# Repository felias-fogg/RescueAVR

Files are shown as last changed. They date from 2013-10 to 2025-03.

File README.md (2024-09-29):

# RescueAVR





This sketch can resurrect many classic AVR chips with wrong fuse settings using high-voltage (HV) programming. 

Sometimes, you may erroneously set a fuse bit, such as the clock source bit, and then the chip does not respond to ISP programming anymore. In this case, HV programming can help. One can easily reset all fuses to their factory setting, and then ISP programming is possible again. Note that the sketch does not implement a general HV programmer but can only perform some basic tasks, such as fuse setting and erasing the entire chip. Furthermore, you should not apply this technique "in-system" without pre-cautions. HV programming means that you apply 12 V to the RESET pin. So, if you do that "in-system," you should make sure that the RESET line is not connected to the rest of the system (e.g., by a pull-up resistor). 

To do HV programming, you need an Arduino Uno, Nano, Pro Mini, Leonardo, or Mega(2560), a breadboard, a PNP/NPN transistor pair, a few resistors, many jumper wires, and an external regulated 12-volt supply. If you are the happy owner of a *RecueAVR shield* for an Arduino Uno/Mega, everything is already included and set up, including the 12 V source. You can build such a shield using the KiCAD design files in the [PCB directory](pcb/) or buy the [PCBs or a kit at Tindie](https://www.tindie.com/products/35748/). The [assembly process](pcb/assembly.md) is straightforward and involves only THT components.

Furthermore, the sketch is also an alternative firmware for [manekinen's Fusebit Doctor](https://web.archive.org/web/20180225102717/http://mdiy.pl/atmega-fusebit-doctor-hvpp/?lang=en). The pin mapping is different between these two versions. When the sketch is compiled for an Arduino Uno, Nano, Pro (Mini), Leonardo, or Mega(2560) in the Arduino IDE, it will use the Arduino Uno pin mapping. Otherwise, it uses the pin mapping for the Fusebit Doctor. One can also force which version is produced by defining the compile-time constants  `ARDUINO_MODE` or `FBD_MODE`, respectively.

By now, the sketch covers 131 different MCU types and has been tested on most of the types that are available in DIP packages.

When using the sketch, remember to set the monitor baud rate to 19200 baud (no parity, 1 stop-bit). A [user manual](docs/manual.md) for the sketch is provided in the docs folder.

The sketch uses many of the ideas and code of [MightyOhm's HV Rescue Shield 2](https://mightyohm.com/blog/products/hv-rescue-shield-2-x/) and is inspired by [manekinen's Fusebit Doctor](https://web.archive.org/web/20180225102717/http://mdiy.pl/atmega-fusebit-doctor-hvpp/?lang=en).

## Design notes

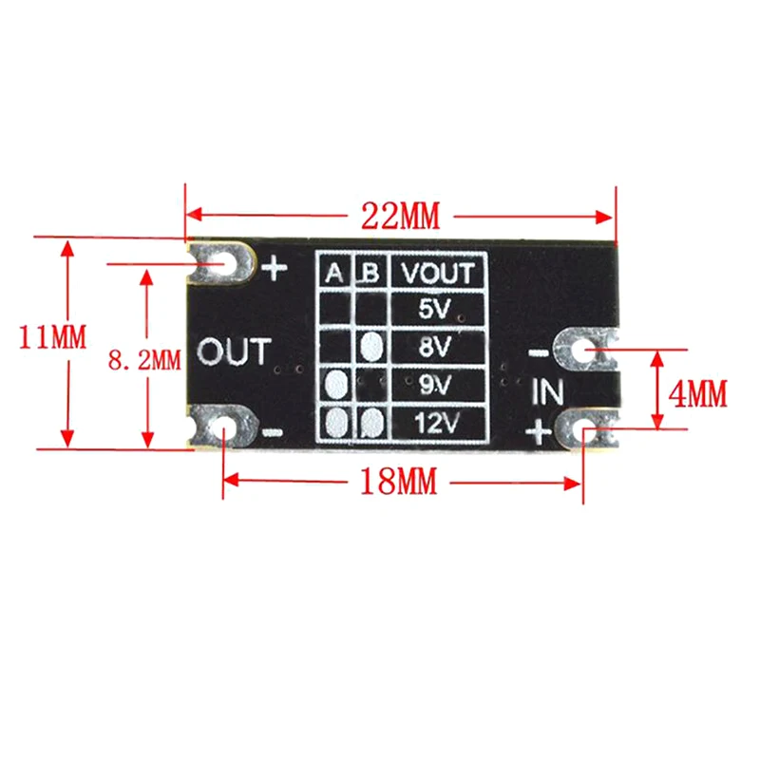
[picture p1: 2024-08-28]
pcb/boost.jpg

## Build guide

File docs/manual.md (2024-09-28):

# RescueAVR Manual

The RescueAVR sketch can be used to rescue bricked AVR MCUs. You can run it on a UNO (or similar) with the target chip on a breadboard, or you can use it to drive the [RescueAVR shield (+ adapter board)](../pcb/), which [you can buy at Tindie](https://www.tindie.com/products/fogg/rescueavr-hv-fuse-programmer-for-avrs/). Finally, it can be used as an alternative firmware for the [Fusebit Doctor](https://web.archive.org/web/20180225102717/http://mdiy.pl/atmega-fusebit-doctor-hvpp/?lang=en).

One word of caution: Since the GPIO pins of two different MCUs will be directly connected to each other, you should upload the sketch __before__ connecting the target chip to the UNO board (or plugging in the RescueAVR shield). Otherwise, you risk short-circuiting a GPIO pin with an active high level to GND, which might destroy the chip.

Remember to set the monitor baud rate to 19200 baud (no parity, 1 stop-bit) when you use the sketch.

### Using RescueAVR on an Arduino Uno with a Breadboard

Below, you will find Fritzing wiring schemes for an ATtiny85, an ATtiny84, and an ATmega328. The complete list of supported chips can be found in [Appendix A](#appendixa). For chips other than the ATtinyX5, ATtinyX4, and ATmega(X)8, you need to consult the particular microcontroller's datasheet. The pin mapping can be found in the Memory Programming Section of each data sheet. For some popular MCUs, I have included wiring instructions for the DIP/SOIC versions of the chips in [Appendix B](#appendixb).

The most crucial part of high-voltage programming is the ability to put 12 volts into the RESET pin of the MCU. So, you need a regulated 12-volt supply and an electronic switch that applies this voltage to the RESET pin. Such a switch using two transistors is shown below. The transistors I have used are pretty standard ones. You can use any other reasonable type. But make sure that the pins are ordered as in the picture, i.e., CBE (otherwise, the Fritzing diagram is incorrect).

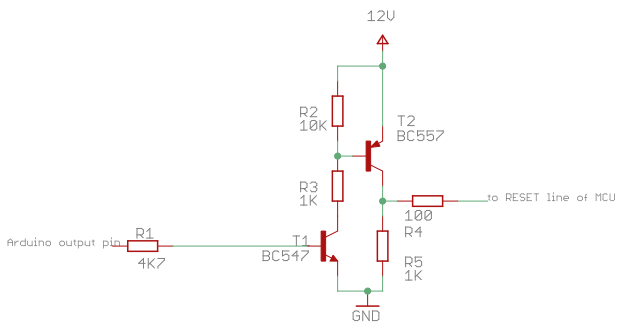
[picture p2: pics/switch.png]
12V switch


The wiring is straightforward for small ATtinys because they use serial programming, and you need only a few wires. The Fritzing diagram for an ATtinyX5 looks as follows (and applies to ATtiny11, 12, 13, 22, and most other 8-pin MCUs).
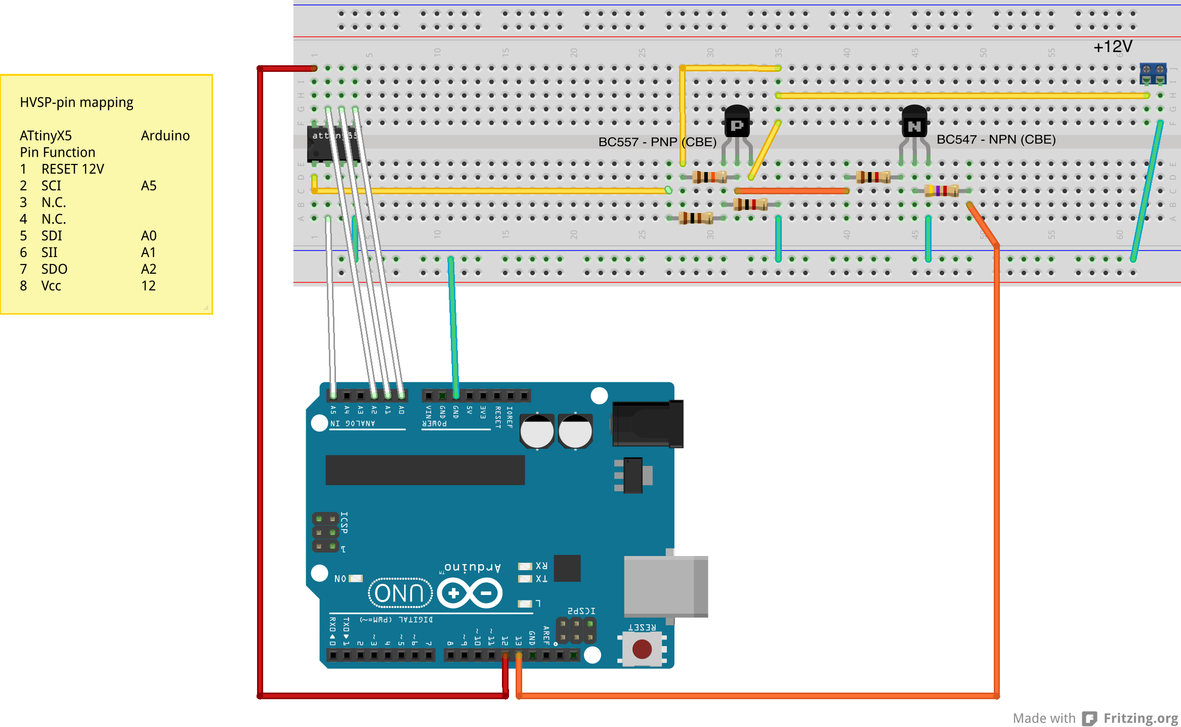
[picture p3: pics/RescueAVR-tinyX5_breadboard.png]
ATtinyX5 Fritzing sketch


Similarly, the wiring for an ATtinyX4 is quite simple as well. As you can see, one needs just 2 data lines (SDI, SDO), one clock line (SCI), and one control line (SII), and in addition, one has to switch the RESET line and the Vcc line. 
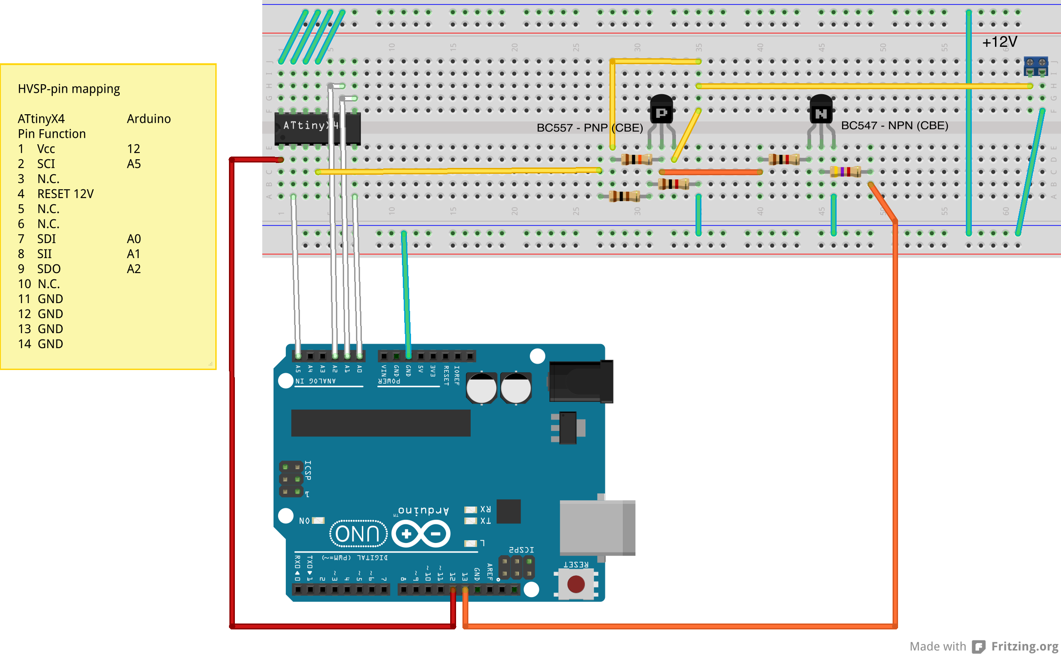
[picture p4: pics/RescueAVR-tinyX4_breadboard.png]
ATtinyX4 Fritzing sketch


The wiring for an ATmegaX8 MCU is much more involved. One has to deal with 8 data lines, one clock line, and 9 control lines! This may look like the following Fritzing diagram.
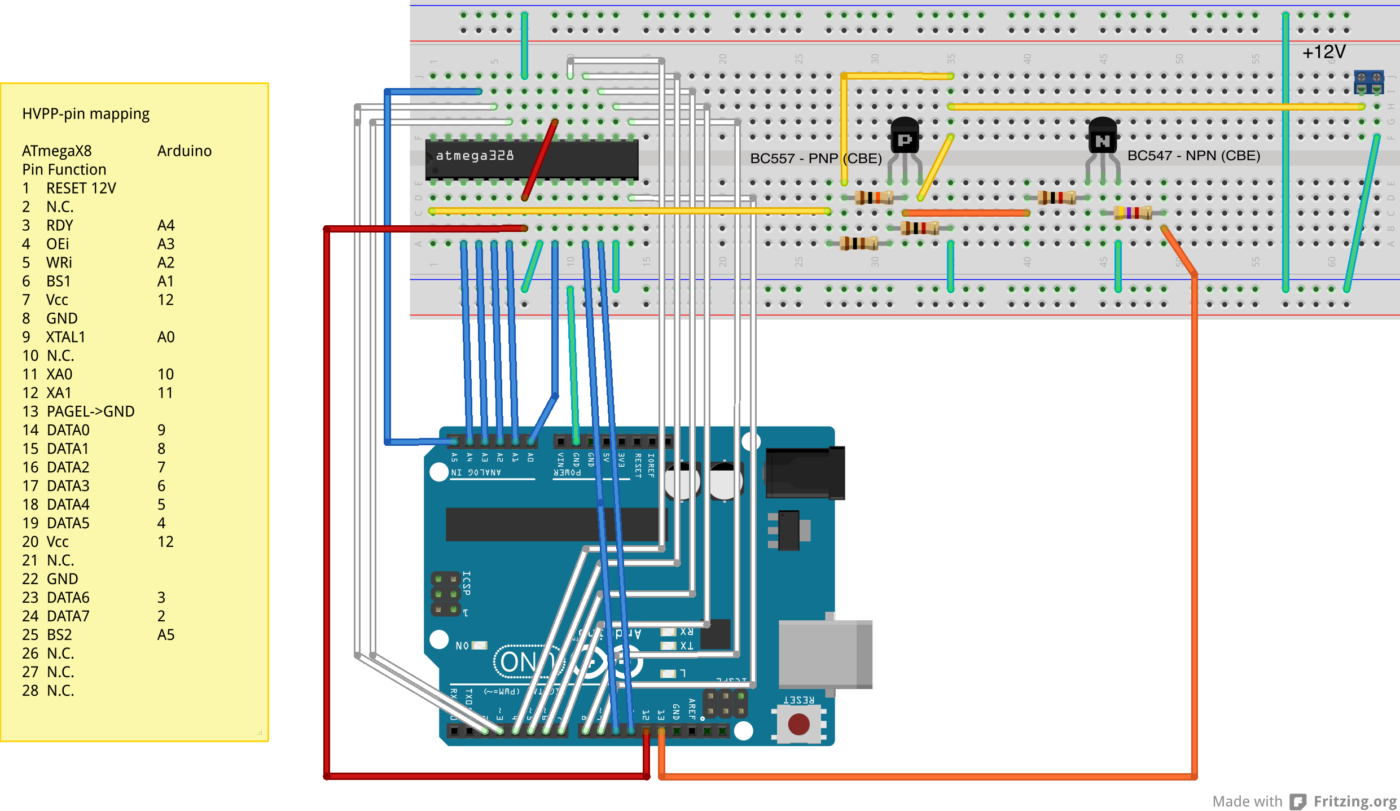
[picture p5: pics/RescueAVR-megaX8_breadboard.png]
ATmega Fritzing sketch


When this is put to work in reality, it can look as follows. Check the wiring twice before applying the external power. If 12 volt is applied to a pin that is not the RESET pin, the chip may easily die.


After you have made all the connections (and double-checked them!), open the Arduino monitor window, switch to 19200 baud, switch on the external power supply, and press the reset button of the Arduino UNO. You are now in interactive rescue mode and can do many things (see below).

### Using RescueAVR with a RescueAVR Shield

The RescueAVR shield can be directly plugged into an Arduino UNO board. It has an onboard step-up converter, so you do not need an external voltage source for high-voltage programming. It provides two SIL sockets for HVPP and HVSP. In addition, it contains DIP sockets for the ATinyX5 series, the ATtinyX4 series, and the ATmega(X)8 series. 

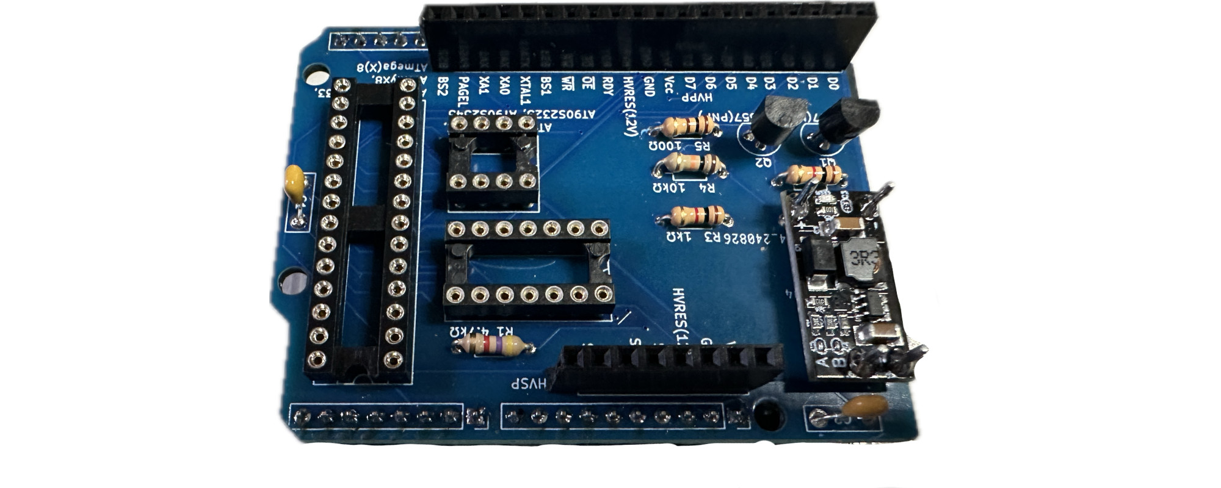
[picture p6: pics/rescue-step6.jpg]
RescueAVR


For the ATtinyX6(1) series, the ATtiny(X)232 series, the ATmegaX3, X4, 8535, the ATmega162, 8515, and pin-compatible chips, one can use an adapter board that plugs into the HVPP/HVSP pin sockets. 

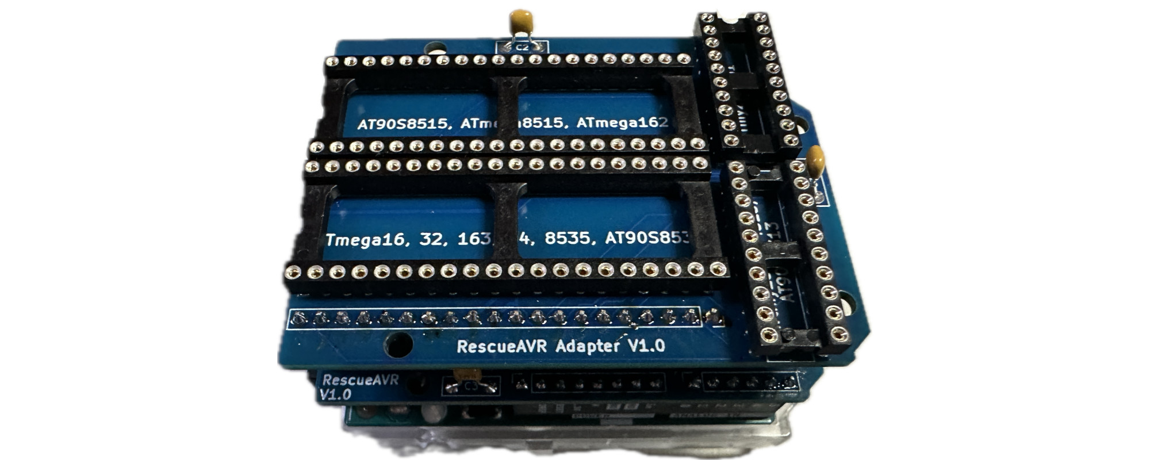
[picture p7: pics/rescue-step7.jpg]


Before you plug in the target chip, you should plug in the shield on the UNO. After connecting the UNO board to a PC, you will enter interactive rescue mode, as described below.

### Using RescueAVR on the Fusebit Doctor

The Fusebit Doctor can be run stand-alone or connected to a computer. In the stand-alone mode (no serial communication lines connected to a computer), after power-up, all LEDs are off, and you can insert a chip. After pressing the button, the board will first try to recognize the chip:

- The green LED is on for three seconds: chip has been successfully recognized,
- the green LED is on for one second, and then the red LED is on for three seconds: The chip has been recognized, but there is not enough information in the firmware to resurrect it,
- the red LED is on for three seconds: no chip has been recognized.

After recognizing the MCU, the board checks whether any lock bits are set. If this is not the case, it tries to set the fuses to a safe default setting. If successful, the green LED flashes for 5 seconds; otherwise, the red LED flashes for 5 seconds. If unsuccessful, you can try to set the erase jumper, which allows for erasing the entire chip (including the lock bits) in order to recover it.

If the board's serial line is connected to a computer using 19200 baud (no parity, 1 stop-bit), you can use the ***interactive rescue mode***, which gives you more control than the stand-alone mode.

### Interactive Rescue Mode

To use RescueAVR in interactive mode, you should be connected to the Fusebit Doctor or Arduino by a serial line with 19200 baud, 1 stop bit, and no parity. This can be accomplished using the Arduino monitor window or any serial line client (e.g., cu, screen, or PuTTY). 

When switched on or after a reset, the sketch will try to determine what kind of programming mode the MCU uses and which MCU is connected. If unsuccessful, the following is displayed:

	No chip found!
	Insert chip and restart or give details.
	
	Choose from:
		P - HVPP
		T - HVPP for Tiny
		S - HVSP
		1 - HVSP for Tiny15
		R - Start again
	Choice: 

When this message is shown, you either forget to insert the MCU, the wiring is wrong, the external power supply is not switched on, or the chip is badly damaged. In the latter case, you might try then to select the programming mode, where *HVPP* is the high-voltage *parallel* programming mode for ATmegas, *HVPP for Tiny* is the same mode for ATtinys (PAGEL and BS1 are both controlled by BS1, and BS2 and XA1 are both controlled by BS2, so PAGEL and XA1 should not be connected to the chip). *HVSP* is the high-voltage *serial* programming mode for ATtinyX4(1) and 8-pin chips, *HVSP for Tiny15* is the serial mode for the ATtiny15. After selecting a programming mode, you can set fuses and lock bits. However, I have never been successful when the MCU could not be identified anymore. In any case, there is more likely a wiring error, or you forgot to plug the MCU into the socket (or breadboard).

Usually, the chip is detected, and something along the following lines is printed.

	Signature: 1E910A
	MCU name:  ATtiny2313
	HV type:   HVPP for Tiny
	Current L/H/E-Fuses: 63 DF FF 
	Default L/H/E-Fuses: 62 DF FF 
	Current lock byte:   FF 
	Oscillator calibr.:  61 

You can then choose from the following menu.

	Choose:
		T - Try to resurrect chip by all means
		E - Erase chip
		D - Burn default fuse values
		L - Change low fuse
		H - Change high fuse
		X - Change extended fuse
		K - Change lock byte
		R - Restart
	Action: 

If you are only interested in unbricking your chip, press 'T'. This will check whether lock bits are set, and if so, it will try to erase the chip (if the 'chip erase' jumper on the Fuse-Doctor board is set). After that, it will try to reset the fuses to their default value. If 'T' does not help, you can say 'goodbye' to the chip. 

The other options are all self-explanatory. If you want to change individual fuses, you may wish to consult the online fuse calculator [AVR Fuse Calculator](https://www.engbedded.com/fusecalc/) by Mark Hämmerling or the chip datasheet. The same goes for the lock byte.

When using the Arduino monitor window, you can enter a new fuse value immediately after the command. For example, typing `L7F` will change the low fuse to 0x7F (if possible).

### Appendix A: Supported MCUs

The sketch works with all currently available *classic* AVR chips (i.e., mainly those that can be programmed using ISP) and a few obsolete ones. Here is the list of supported MCUs (currently 131). The **bold** ones can be programmed using the RescueAVR shield by plugging the chip with a DIP footprint into one of the shield IC sockets. I have tested the *italics* ones.

- AT90CAN32, AT90CAN64, AT90CAN128
- AT90PWM1/AT90PWM2B/AT90PWM3B
- AT90PWM2/AT90PWM3
- AT90PWM216/AT90PWM316
- AT90PWM81, ATP90WM161
- AT90USB646/7, AT90USB1286/7
- AT90USB82, AT90USB162
- **AT90S1200,** ***AT90S2313***
- **AT90S2333, *AT90S4433***
- ***AT90S2323*, AT90S2343**
- **AT90S4434, *AT90S8535***
- **AT90S4414**, ***AT90S8515***
- ___ATtiny11___
- ***ATtiny12***
- **ATtiny22**
- ***ATtiny13***
- ATtiny43U
- ***ATtiny2313***, ***ATtiny4313***
- ***ATtiny24***, ***ATtiny44***, ***ATtiny84***
- *ATtiny441*, ATtiny841
- *ATtiny15*, 
- ***ATtiny25*, *ATtiny45*, *ATtiny85*** 
- ***ATtiny2*6**
- ***ATtiny261*, *ATtiny461*, *ATtiny861***
- ATtiny87, ATtiny167
- **ATtiny28**
- ***ATtiny48*, *ATtiny88***
- ATtiny828
- ATtiny1634
- ***ATmega8515***
- ***ATmega8535***
- ***ATmega8***, ATmega8HVA, ATmega8HVB
- **ATmega16**, ATmega16HVA, ATmega16HVB, ATmega16M1, ***ATmega32***, ATmega32C1, ATmega32M1, ATmega32HVB, ATmega64, ATmega64C1, ATmega64HEV2, ATmega64M1, ATmega64RFR2, ATmega128, ATmega128RFA1, ATmega128RFR2, ATmega256RFR2
- ATmega640, ATmega1280, ATmega1281, ATmega2560, ATmega2561
- **ATmega161**, ***ATmega162***
- ATmega103
- ***ATmega163***, **ATmega323**
- **ATmega164, ATmega164P, ATmega324, ATmega324P**, Atmega324PB, **ATmega644, ATmega644P**, ATmega644RFR2, **ATmega1284, *ATmega1284P*,** ATmega1284RFR2, ATmega2564RFR2
- ATmega165, ATmega165P, ATmega325, ATmega325P, ATmega3250, ATmega3250P, ATmega645, ATmega645P, ATmega6450, ATmega6450P
- ATmega406
- ***ATmega48*, *ATmega48P*,** ATmega48PB, ***ATmega88***, ***ATmega88P***, ATmega88PB, ***ATmega168*, *ATmega168P*,** ATmega16PB, ***ATmega328***, ***ATmega328P***, ATmega328PB
- ATmega169, ATmega169P, ATmega329, ATmega329P, ATmega3290, ATmega3290P, ATmega649, ATmega649P, ATmega6490, ATmega6490P
- ATmega8U2, ATmega16U2, ATmega32U2
- ATmega16U4, ATmega32U4

### Appendix B: Wiring tables for DIP/SOIC variants of some MCUs

The wiring tables below apply only to the SOIC/DIP versions of the respective MCU types. 

#### ATtiny11, 12, 13, 22, 25, 45, 85, AT90S2323, 2343 (HVSP)

| ATtiny pin | Function | Arduino UNO pin name |
| --- | --- | --- |
| 1 | !RESET(12V switchable) | (triggered by 13) |
| 2 | SCI | A5 |
| 3 | | |
| 4 | GND | GND |
| 5 | SDI | A0 |
| 6 | SII | A1 |
| 7 | SDO | A2 |
| 8 | Vcc | 12 |

#### ATtiny15 (HVSP for Tiny15)

| ATtiny pin | Function | Arduino UNO pin name |
| --- | --- | --- |
| 1 | !RESET(12V switchable) | (triggered by 13) |
| 2 | | |
| 3 | SCI | A5 |
| 4 | GND | GND |
| 5 | SDI | A0 |
| 6 | SII | A1 |
| 7 | SDO | A2 |
| 8 | Vcc | 12 |

#### ATtiny24, 44, 84, 441, 841 (HVSP)

| ATtiny pin | Function | Arduino UNO pin name |
| --- | --- | --- |
| 1 | Vcc | 12 |
| 2 | SCI | A5 |
| 3 | | |
| 4 | !RESET(12V) | (triggered by 13) |
| 5 | | |
| 6 | | |
| 7 | SDI | A0 |
| 8 | SII | A1 |
| 9 | SDO | A2 |
| 10 | | |
| 11 | GND | |
| 12 | GND | |
| 13 | GND | |
| 14 | GND | |

#### ATtiny2313 and 4313, AT90S1200, 2313 (tiny HVPP)

| ATtiny Pin | Function | Arduino UNO pin name |
| --- | --- | --- |
| 1 | !RESET  (12V switchable) | (triggered by 13) |
| 2 | | |
| 3 | RDY | A4 |
| 4 | | |
| 5 | XTAL1 | A0 |
| 6 | !OE | A3 |
| 7 | !WR | A2 |
| 8 | **BS1**/PAGEL | A1 |
| 9 | XA0 | 10 |
| 10 | GND | GND |
| 11 | XA1/**BS2** | A5 |
| 12 | DATA0 | 9 |
| 13 | DATA1 | 8 |
| 14 | DATA2 | 7 |
| 15 | DATA3 | 6 |
| 16 | DATA4 | 5 |
| 17 | DATA5 | 4 |
| 18 | DATA6 | 3 |
| 19 | DATA7 | 2 |
| 20 | Vcc (5V) | 12 |

#### ATtiny26, ATtiny261, ATtiny461, ATtiny861 (tiny HVPP)

| ATtiny pin | Function | Arduino pin name  |
| --- | --- | --- |
| 1 | !WR | A2 |
| 2 | XA0 | 10 |
| 3 | XA1/**BS2** | A5 |
| 4 | PAGEL/**BS1** | A1 |
| 5 | Vcc(5V) | 12 |
| 6 | GND | GND |
| 7 | XTAL1 | A0 |
| 8 | !OE | A3 |
| 9 | RDY | A4 |
| 10 | !RESET(12V) | (triggered by 13) |
| 11 | DATA7 | 2 |
| 12 | DATA6 | 3 |
| 13 | DATA5 | 4 |
| 14 | DATA4 | 5 |
| 15 | Vcc(5V) | 12 |
| 16 | GND | GND |
| 17 | DATA3 | 6 |
| 18 | DATA2 | 7 |
| 19 | DATA1 | 8 |
| 20 | DATA0 | 9 |

#### ATtiny87, ATtiny167 (tiny HVPP)

| ATtiny pin | Function | Arduino UNO pin name |
| --- | --- | --- |
| 1 | DATA0 | 9 |
| 2 | DATA1 | 8 |
| 3 | DATA2 | 7 |
| 4 | DATA3 | 6 |
| 5 | Vcc(5V) | 12 |
| 6 | GND | GND |
| 7 | DATA4 | 5 |
| 8 | DATA5 | 4 |
| 9 | DATA6 | 3 |
| 10 | DATA7 | 2 |
| 11 | | |
| 12 | RDY | A4 |
| 13 | !OE | A3 |
| 14 | XTAL1 | A0 |
| 15 | Vcc(5V) | 12 |
| 16 | GND | GND |
| 17 | PAGEL/**BS1** | A1 |
| 18 | XA1/**BS2** | A5 |
| 19 | XA0 | 10 |
| 20 | !WR | A2 |

#### ATtiny1634 (tiny HVPP)

| ATtiny pin | Function | Arduino UNO pin name |
| --- | --- | --- |
| 1 | | |
| 2 | DATA7 | 2 |
| 3 | DATA6 | 3 |
| 4 | DATA5 | 4 |
| 5 | DATA4 | 5 |
| 6 | DATA3 | 6 |
| 7 | DATA2 | 7 |
| 8 | DATA1 | 8 |
| 9 | DATA0 | 9 |
| 10 | GND | GND |
| 11 | Vcc(5V) | 12 |
| 12 | XTAL | A0 |
| 13 | | |
| 14 | | |
| 15 | !RESET(12V) | (triggered by 13) |
| 16 | !OE | A3 |
| 17 | !WR | A2 |
| 18 | **BS1**/PAGEL | A1 |
| 19 | XA0 | 10 |
| 20 | XA1/**BS2** | A5 |

#### ATtinyX8, ATmega8, ATmegaX8, AT90S2333, 4433 (HVPP)

| ATmega pin | Function | Arduino UNO pin name |
| --- | --- | --- |
| 1 | !RESET(12V) | (triggered by 13) |
| 2 | | |
| 3 | RDY | A4 |
| 4 | !OE | A3 |
| 5 | !WR | A2 |
| 6 | BS1 | A1 |
| 7 | Vcc | 12 |
| 8 | GND | GND |
| 9 | XTAL1 | A0 |
| 10 | | |
| 11 | XA0 | 10 |
| 12 | XA1 | 11 |
| 13 | PAGEL (not AT90SX33) | GND |
| 14 | DATA0 | 9 |
| 15 | DATA1 | 8 |
| 16 | DATA2 | 7 |
| 17 | DATA3 | 6 |
| 18 | DATA4 | 5 |
| 19 | DATA5 | 4 |
| 20 | Vcc | 12 |
| 21 | | |
| 22 | GND | GND |
| 23 | DATA6 | 3 |
| 24 | DATA7 | 2 |
| 25 | BS2 (not AT90SX33) | A5 |
| 26 | | |
| 27 | | |
| 28 | | |

#### ATmega16, ATmega32, ATmegaX3, ATmegaX4,  ATmega8535, AT90S8535 (HVPP)

| ATmega pin | Function | Arduino UNO pin name |
| --- | --- | --- |
| 1 | DATA0 | 9 |
| 2 | DATA1 | 8 |
| 3 | DATA2 | 7 |
| 4 | DATA3 | 6 |
| 5 | DATA4 | 5 |
| 6 | DATA5 | 4 |
| 7 | DATA6 | 3 |
| 8 | DATA7 | 2 |
| 9 | !RESET(12V) | (triggered by 13) |
| 10 | Vcc(5V) | 12 |
| 11 | GND | GND |
| 12 | | |
| 13 | XTAL1 | A0 |
| 14 | | |
| 15 | RDY | A4 |
| 16 | !OE | A3 |
| 17 | !WR | A2 |
| 18 | BS1 | A1 |
| 19 | XA0 | 10 |
| 20 | XA1 | 11 |
| 21 | PAGEL (only ATmega) | GND |
| 22 | | |
| 23 | | |
| 24 | | |
| 25 | | |
| 26 | | |
| 27 | | |
| 28 | | |
| 29 | | |
| 30 | Vcc(5V) | 12 |
| 31 | GND | GND |
| 32 | | |
| 33 | | |
| 34 | | |
| 35 | | |
| 36 | | |
| 37 | | |
| 38 | | |
| 39 | | |
| 40 | BS2 (only ATmega) | A5 |

#### AT90S4414, 8515, ATmega8515, 161, 162 (HVPP)

| ATmega pin | Function | Arduino pin name  |
| --- | --- | --- |
| 1 | DATA0 | 9 |
| 2 | DATA1 | 8 |
| 3 | DATA2 | 7 |
| 4 | DATA3 | 6 |
| 5 | DATA4 | 5 |
| 6 | DATA5 | 4 |
| 7 | DATA6 | 3 |
| 8 | DATA7 | 2 |
| 9 | !RESET(12V) | (triggered by 13) |
| 10 | | |
| 11 | RDY | A4 |
| 12 | !OE | A3 |
| 13 | !WR | A2 |
| 14 | BS1 | A1 |
| 15 | XA0 | 10 |
| 16 | XA1 | 11 |
| 17 | PAGEL (only ATmega) | GND |
| 18 | | |
| 19 | XTAL1 | A0 |
| 20 | GND | GND |
| 21 | | |
| 22 | | |
| 23 | | |
| 24 | | |
| 25 | | |
| 26 | | |
| 27 | | |
| 28 | | |
| 29 | | |
| 30 | | |
| 31 | | |
| 32 | | |
| 33 | | |
| 34 | | |
| 35 | | |
| 36 | | |
| 37 | | |
| 38 | | |
| 39 | BS2 (only ATmega) | A5 |
| 40 | Vcc(5V) | 12 |

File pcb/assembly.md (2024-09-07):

# RescueAVR Assembly

The basic kit and the full kit kit [can be bought at Tindie](https://www.tindie.com/products/fogg/rescueavr-hv-fuse-programmer-for-avrs/).

The basic kit consists of:

- one RescueAVR PCB
- one RescueAVR Adapter PCB
- one GTIWUNG Step-Up Converter (5V/12V)
- four soldering pins (to connect the step-up converter to the RescueAVR PCB)

The full kit contains in addition:

- one 8-pin IC socket
- one 14-pin IC socket
- one 28-pin (narrow) IC socket
- two 20-pin IC sockets
- two 40-pin IC sockets
- two 40-pin pin headers (to be broken up into one 6-pin, three 8-pin, one 10-pin, and one 20-pin header)
- one 8-pin pin socket
- one 20-pin socket
- five 100 nF capacitors
- five resistors (100 Ω, two 1 kΩ, 4.7 kΩ, 10 kΩ)
- one NPN transistor (BC547)
- one PNP transistor (BC557)

### Step 1: Install step-up converter

If the step-up converter is not already installed on the RescueAVR PCB, this is the first step. 

1. Insert the four soldering pins with the shorter side into the PCB.
2. Make sure the pins are straight and that the tip protrudes on the backside.
3. Place the step-up converter with the component side upwards on the pins.
4. Solder the pins to the step-up converter.
5. Solder the pins on the backside of the PCB.

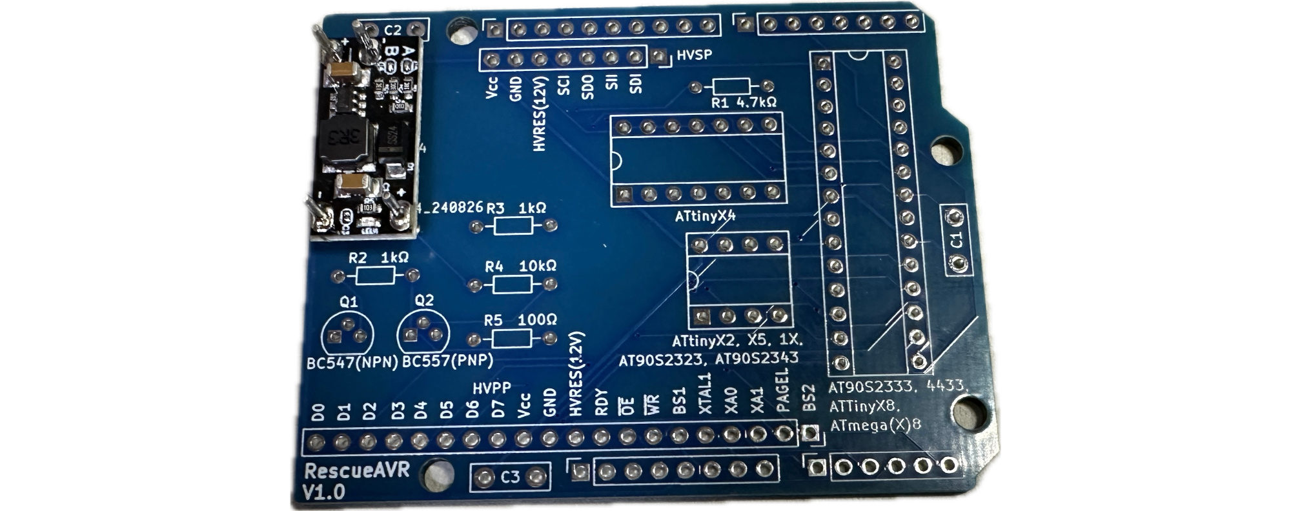
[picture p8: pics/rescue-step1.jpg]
Step1


### Step 2: Solder resistors

Solder the five resistors:

1. R1: 4.7 kΩ (yellow-violet-red)
2. R2: 1 kΩ (brown-black-red)
3. R3: 1 kΩ (brown-black-red)
4. R4: 10 kΩ (brown-black-orange)
5. R5: 100 Ω (brown-black-brown)

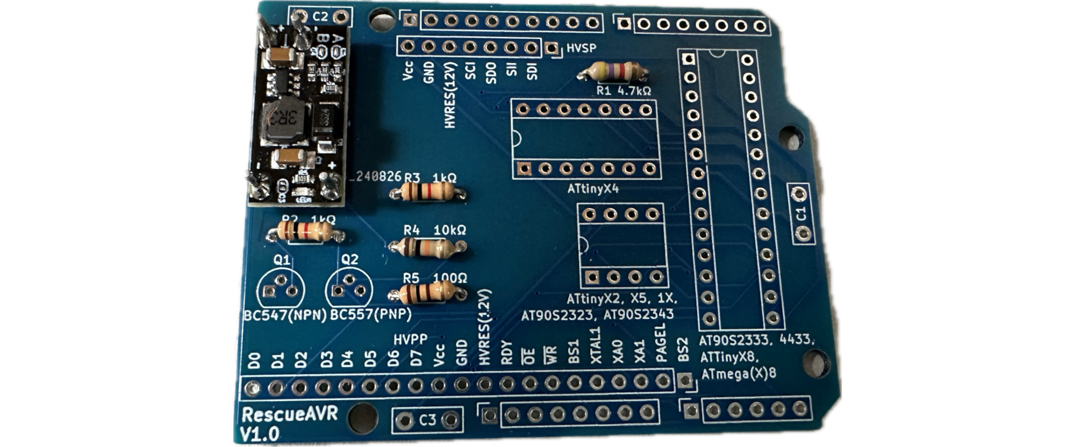
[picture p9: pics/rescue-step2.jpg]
Step2


### Step 3: Solder capacitors and transistors

1. Q1: BC547 (NPN)
2. Q2: BC557 (PNP)
3. C1-C3: 100 nF

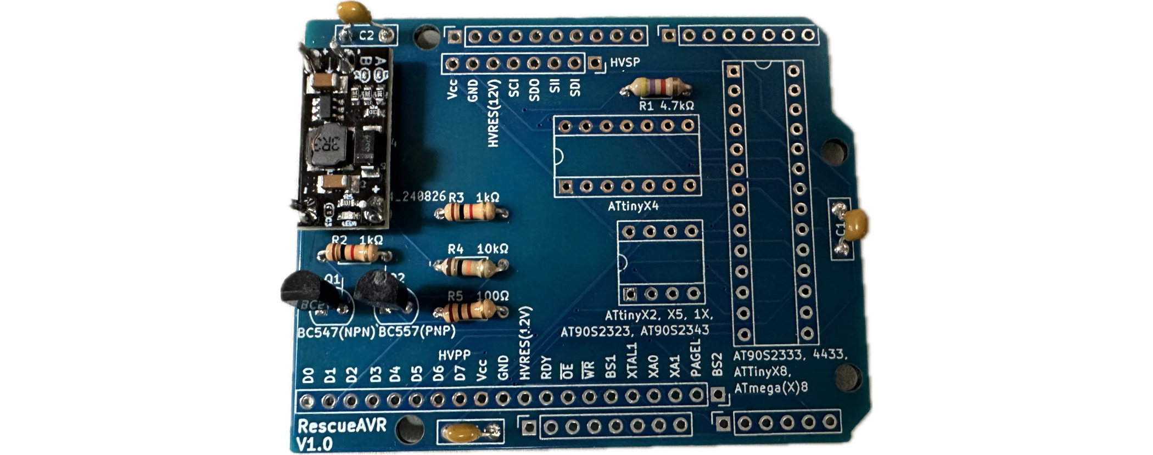
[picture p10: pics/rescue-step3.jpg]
Step3


### Step 4: Solder Arduino pin headers

Soldering the Arduino pin headers is preferrably done by placing the pin headers into the the pin sockets of an UNO and then placing the RescueAVR PCB on top of it. This way, you make sure that the pin headers are perfectly aligned.

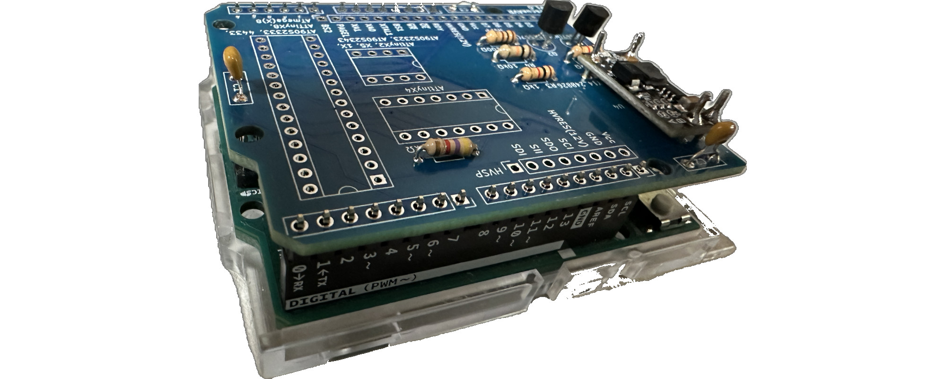
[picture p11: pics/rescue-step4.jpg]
Step4


### Step 5: Solder IC sockets

Insert the 8-pin, 14-pin, and 28-pin sockets into the PCB and solder them. Make sure to align the notches with the notches on the silkscreen. 

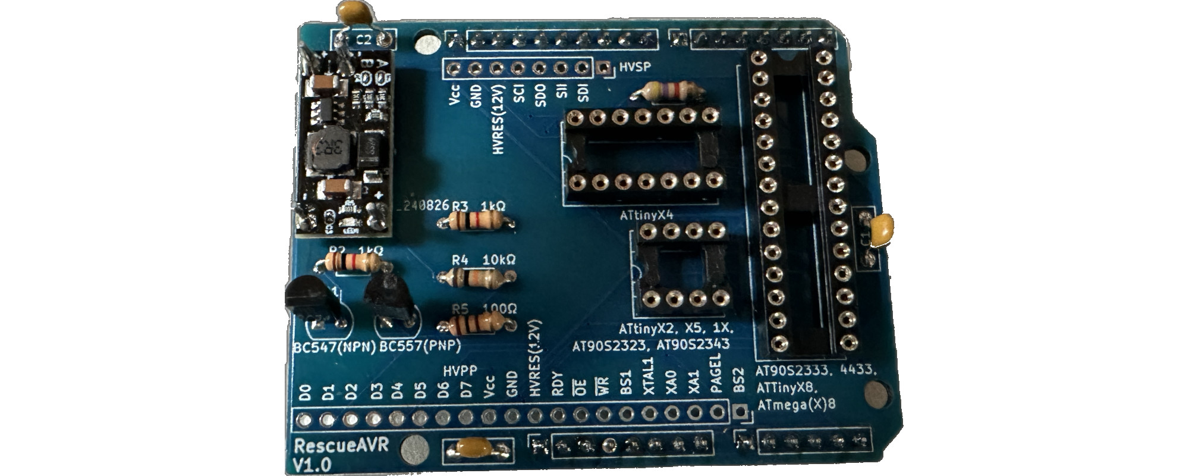
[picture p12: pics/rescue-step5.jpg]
Step5


### Step 6: Solder the pin sockets and the pin headers for the adapters

In order to ensure alignment, put the pinheaders into the sockets, put the socketes into the RescueAVR PCB and then put the adpater PCB on top. Now solder the pin sockets and headers. 

Step6

### Step 7: Solder IC sockets and capacitors to adapter

While soldering the two 40-pin and 20-pin sockets, ensure the notches align. 

Step7

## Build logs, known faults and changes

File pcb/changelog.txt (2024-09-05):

RescueAVR:

V1.0

- initial release

V1.1 (6.9.2024)

- modified silkscreen and 3D model

- removed ATtiny15

ReascueAVR Adapter:

V1.0

- initial release

V1.1

- added silkscreen: ATMega161, ATmegaX3, AT90S1200, AT90S4414

V1.2 (6.9.2024)

- moved silkscreen to the side so that it is always readable, modified
  3D model

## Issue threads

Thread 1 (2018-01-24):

Arduino IDE 1.8.5

bobybobybob, 2018-01-24:
Hello,
today i have repair my µC with your cable and code.  Work perfekt, thank you.

The new Arduino IDE give compiler error...  only have to add  const  on all

// The names of all MCUs known to us
const char at90s2313[] PROGMEM = "AT90S2313";
const char at90s2333[] PROGMEM = "AT90S2333";
const char at90s2343[] PROGMEM = "AT90S2343";
const char at90s4433[] PROGMEM = "AT90S4433";
const char at90s4434[] PROGMEM = "AT90S4434";
const char at90s8515[] PROGMEM = "AT90S8515";
const char at90s8535[] PROGMEM = "AT90S8535";
const char attiny11[] PROGMEM = "ATtiny11";
const char attiny12[] PROGMEM = "ATtiny12";
const char attiny13[] PROGMEM = "ATtiny13";
const char attiny15[] PROGMEM = "ATtiny15";
const char attiny2313[] PROGMEM = "ATtiny2313";
const char attiny4313[] PROGMEM = "ATtiny4313";
const char attiny24[] PROGMEM = "ATtiny24";
const char attiny44[] PROGMEM = "ATtiny44";
const char attiny84[] PROGMEM = "ATtiny84";
const char attiny25[] PROGMEM = "ATtiny25";
const char attiny45[] PROGMEM = "ATtiny45";
const char attiny85[] PROGMEM = "ATtiny85";
const char attiny26[] PROGMEM = "ATtiny26";
const char attiny261[] PROGMEM = "ATtiny261";
const char attiny461[] PROGMEM = "ATtiny461";
const char attiny861[] PROGMEM = "ATtiny861";
const char attiny28[] PROGMEM = "ATtiny28";
const char attiny48[] PROGMEM = "ATtiny48";
const char attiny88[] PROGMEM = "ATtiny88";
const char atmega8515[] PROGMEM = "ATmega8515";
const char atmega8535[] PROGMEM = "ATmega8535";
const char atmega8[] PROGMEM = "ATmega8";
const char atmega8hva[] PROGMEM = "ATmega8HVA";
const char atmega16[] PROGMEM = "ATmega16";
const char atmega16hva[] PROGMEM = "ATmega16HVA";
const char atmega16hvb[] PROGMEM = "ATmega16HVB";
const char atmega32[] PROGMEM = "ATmega32";
const char atmega32c1[] PROGMEM = "ATmega32C1";
const char atmega32hvb[] PROGMEM = "ATmega32HVB";
const char atmega64[] PROGMEM = "ATmega64";
const char atmega64c1[] PROGMEM = "ATmega64c1";
const char atmega64hev2[] PROGMEM = "ATmega64HEV2";
const char atmega64m1[] PROGMEM = "ATmega64m1";
const char atmega128[] PROGMEM = "ATmega128";
const char atmega128rfa1[] PROGMEM = "ATmega128RFA1";
const char atmega162[] PROGMEM = "ATmega162";
const char atmega48[] PROGMEM = "ATmega48";
const char atmega48p[] PROGMEM = "ATmega48P";
const char atmega88[] PROGMEM = "ATmega88";
const char atmega88p[] PROGMEM = "ATmega88P";
const char atmega168[] PROGMEM = "ATmega168";
const char atmega168p[] PROGMEM = "ATmega168P";
const char atmega328[] PROGMEM = "ATmega328";
const char atmega164a[] PROGMEM = "ATmega164A";
const char atmega164p[] PROGMEM = "ATmega164P";
const char atmega324a[] PROGMEM = "ATmega324A";
const char atmega324p[] PROGMEM = "ATmega324P";
const char atmega324pa[] PROGMEM = "ATmega324PA";
const char atmega644[] PROGMEM = "ATmega644";
const char atmega644p[] PROGMEM = "ATmega644P";
const char atmega644rfr2[] PROGMEM = "ATmega644RFR2";
const char atmega1284[] PROGMEM = "ATmega1284";
const char atmega1284p[] PROGMEM = "ATmega1284P";
const char atmega1284rfr2[] PROGMEM = "ATmega1284RFR2";
const char atmega328p[] PROGMEM = "ATmega328P";

// table with signatures
// 1st word signature (w/o 1E), 2nd word: MSB number of fuses (or 0 if we do not know),
// 2nd word LSB: low fuse, 3rd word MSB: high fuse, 3rd word LSB: extended fuse,
// 4th word string address.

#define MCU_NUM 62
const uint16_t mcu_types[MCU_NUM][4] PROGMEM =

Closed 2018-02-05.

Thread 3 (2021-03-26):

Atmega 32 pinout

lmeucchi, 2021-03-26:
Hi! How are you?
I have an atmega32 and I think it is locked.I do not know if I can unlock it by programming with hvpp, if it is true, how is the wiring connection?
Thank you greetings

felias-fogg, 2021-03-26:
It's easy. Just google "atmega32". This will give a link to the Atmega32 data sheet. On page 259, you will find the pin mapping for HVPP.

lmeucchi, 2021-03-26:
I think I forgot to see the datasheet jajajaja
There is everything you need to know.Thank you very much for answering, today I am going to try to unlock it.Greetings

Closed 2021-03-26.

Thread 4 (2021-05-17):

Arduino Mega r3

KaySagaragi, 2021-05-17:
i was wondering is possible adapting this project for arduino mega, im interesting to use for rescue from atmega 644A

felias-fogg, 2021-05-17:
Sure! You can run the rescue sketch on an Arduino Mega and it is possible to rescue ATmega644A chips (see datasheets for how to connect the different wires).

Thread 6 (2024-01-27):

RescueAVR

whynot2018, 2024-01-27:
hi
Is it possible to utilize RescueAVR 32pin atmega328p-au? I made an adapter for 28 atmega328p.
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
best regards

felias-fogg, 2024-01-28:
Sure! Just have a look at the ATmega328P datasheet (https://ww1.microchip.com/downloads/aemDocuments/documents/MCU08/ProductDocuments/DataSheets/ATmega48A-PA-88A-PA-168A-PA-328-P-DS-DS40002061B.pdf), Section 28.6 on parallel programming.

whynot2018, 2024-01-30:
Sorry but I don't get it? It's pretty complicated. I have only two digital pins left and I need to add PC[1:0]:PB[5:0]-DATA
PC1
PC0
PB5
PB4
PB3
PB2
PB1
PB0

https://github.com/felias-fogg/RescueAVR/blob/master/RescueAVR-megaX8_breadboard.png
https://images.prismic.io/circuito/8e3a980f0f964cc539b4cbbba2654bb660db6f52_arduino-uno-pinout-diagram.png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,format

ATmega328pSMD 	ARDUINO PRO MINI	Function               ARDUINO UNO
	Pin		               PIN	                               	                       PIN
	1-PD3		       3	    			        WRi     		       A2
	2-PD4		       4	  	  	                BS1     		       A1
	3-GND		       GND         			GND	               GND
	4-VCC		       VCC         			VCC	               12
	5-GND		       GND         			GND         	        GND
	6-VCC		       VCC         			VCC         		12
	7-PB6		       (Q1 CYSTIAL PIN3)        XTAL1   	                A0
	8-PB7		       (Q1 CYSTIAL PIN1)        -     	  		         -
	9-PD5		       5	            	               XA0                          10
	10-PD6		       6	            	               XA1                          11
	11-PD7		       7	            	               PAGEL                     GND
	12-PB0		       8	          	               DATA0	                9
	13-PB1		       9	             	               DATA1	                8
	14-PB2	  	      10 	      	    	               DATA2  	                7
	15-PB3		      11        	  		       DATA3    		        6
	16-PB4		      12        			       DATA4    		        5
	17-PB5		      13	        		       DATA5        	        4
	18-AVCC	       VCC	                               VCC                         12
	19-ADC6               A6	         	               -             		       -
	20-AREF		      -			               -              		       -
	21-GND		      GND		  	              GND		               GND
	22-ADC7	      A7		  	               -	                      -
	23-PC0		      A0        		  	      DATA6	              3
	24-PC1		      A1		          	      DATA7	      	      2
	25-PC2		      A2	        	  	      BS2                         A5
	26-PC3		      A3		           	      -		             -
	27-PC4		      A4		                      -	                     -
	28-PC5		      A5		  	             -                               -
	29-PC6		      RESET		            RESET                    AVR-RST
	30-PD0		      RT1	  	         	    -		                   -
	31-PD1		      TX0		  	            RDY		           A4
	32-PD2		      2	            	  	    OEi 			   A3

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

felias-fogg, 2024-01-30:
Hi,

it is pretty complicated! And with the new AVR chips they pretty much simplified it.

However, your table already shows the correct mapping. DATA0-DATA5 are on PB0-PB5 and DATA6-DATA7 are on PC0-PC1. And they are connected to the right Arduino pins (on which the RescueAVR chip is supposed to run). So, nothing to worry.

felias-fogg, 2024-01-31:
Cool! Tell me, when you successfully reset the chips!

Closed 2024-01-31.

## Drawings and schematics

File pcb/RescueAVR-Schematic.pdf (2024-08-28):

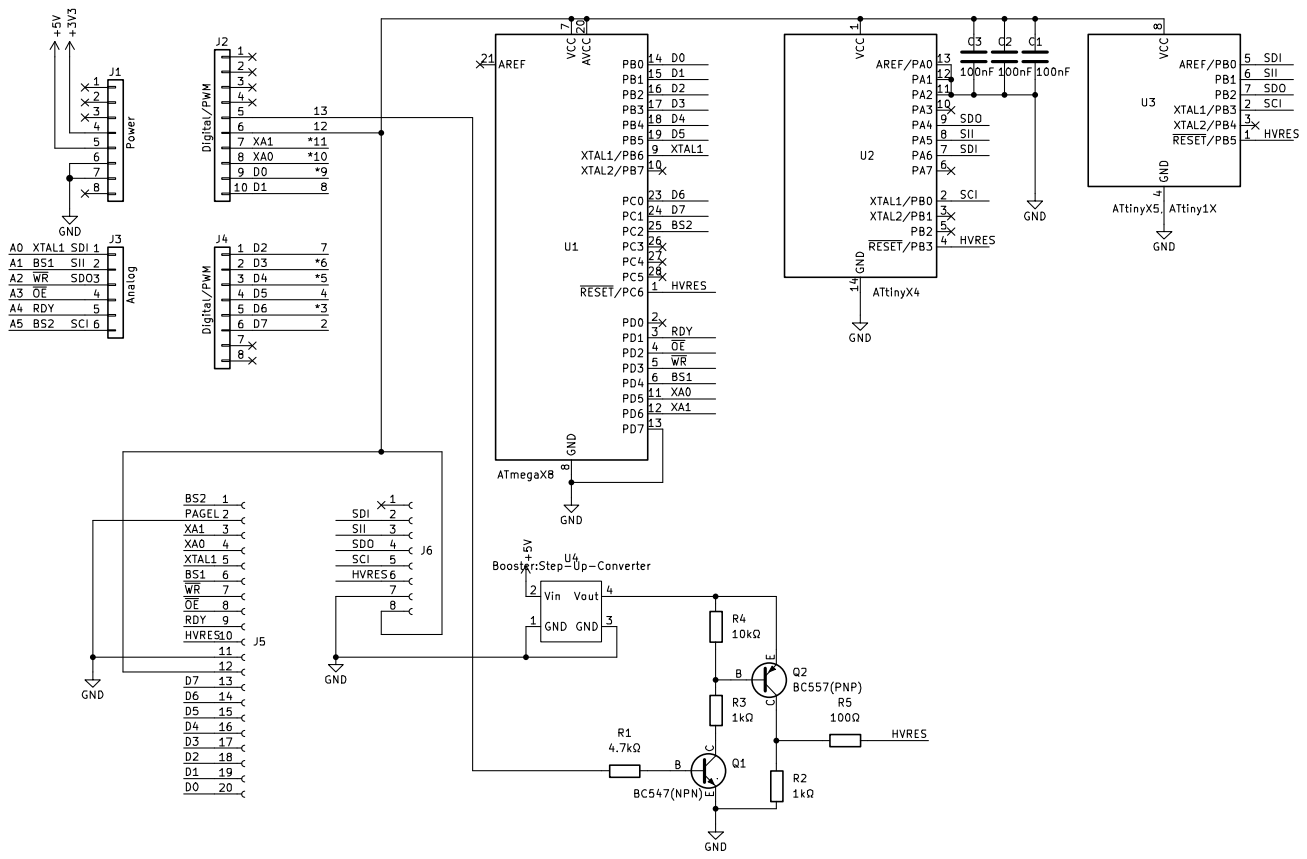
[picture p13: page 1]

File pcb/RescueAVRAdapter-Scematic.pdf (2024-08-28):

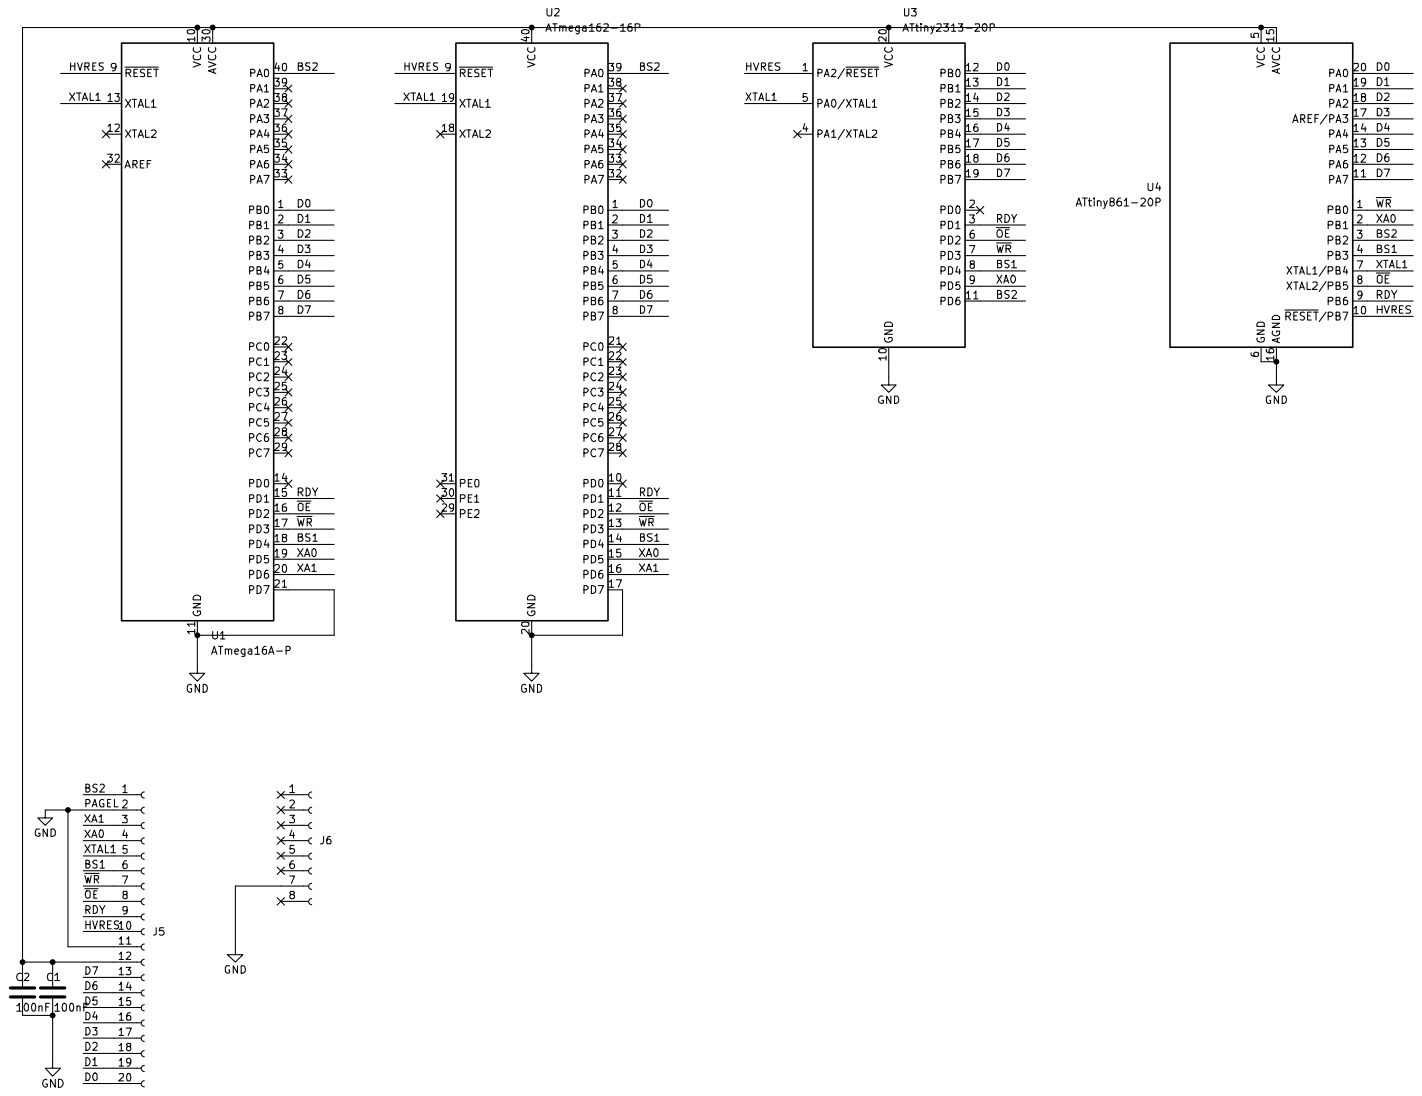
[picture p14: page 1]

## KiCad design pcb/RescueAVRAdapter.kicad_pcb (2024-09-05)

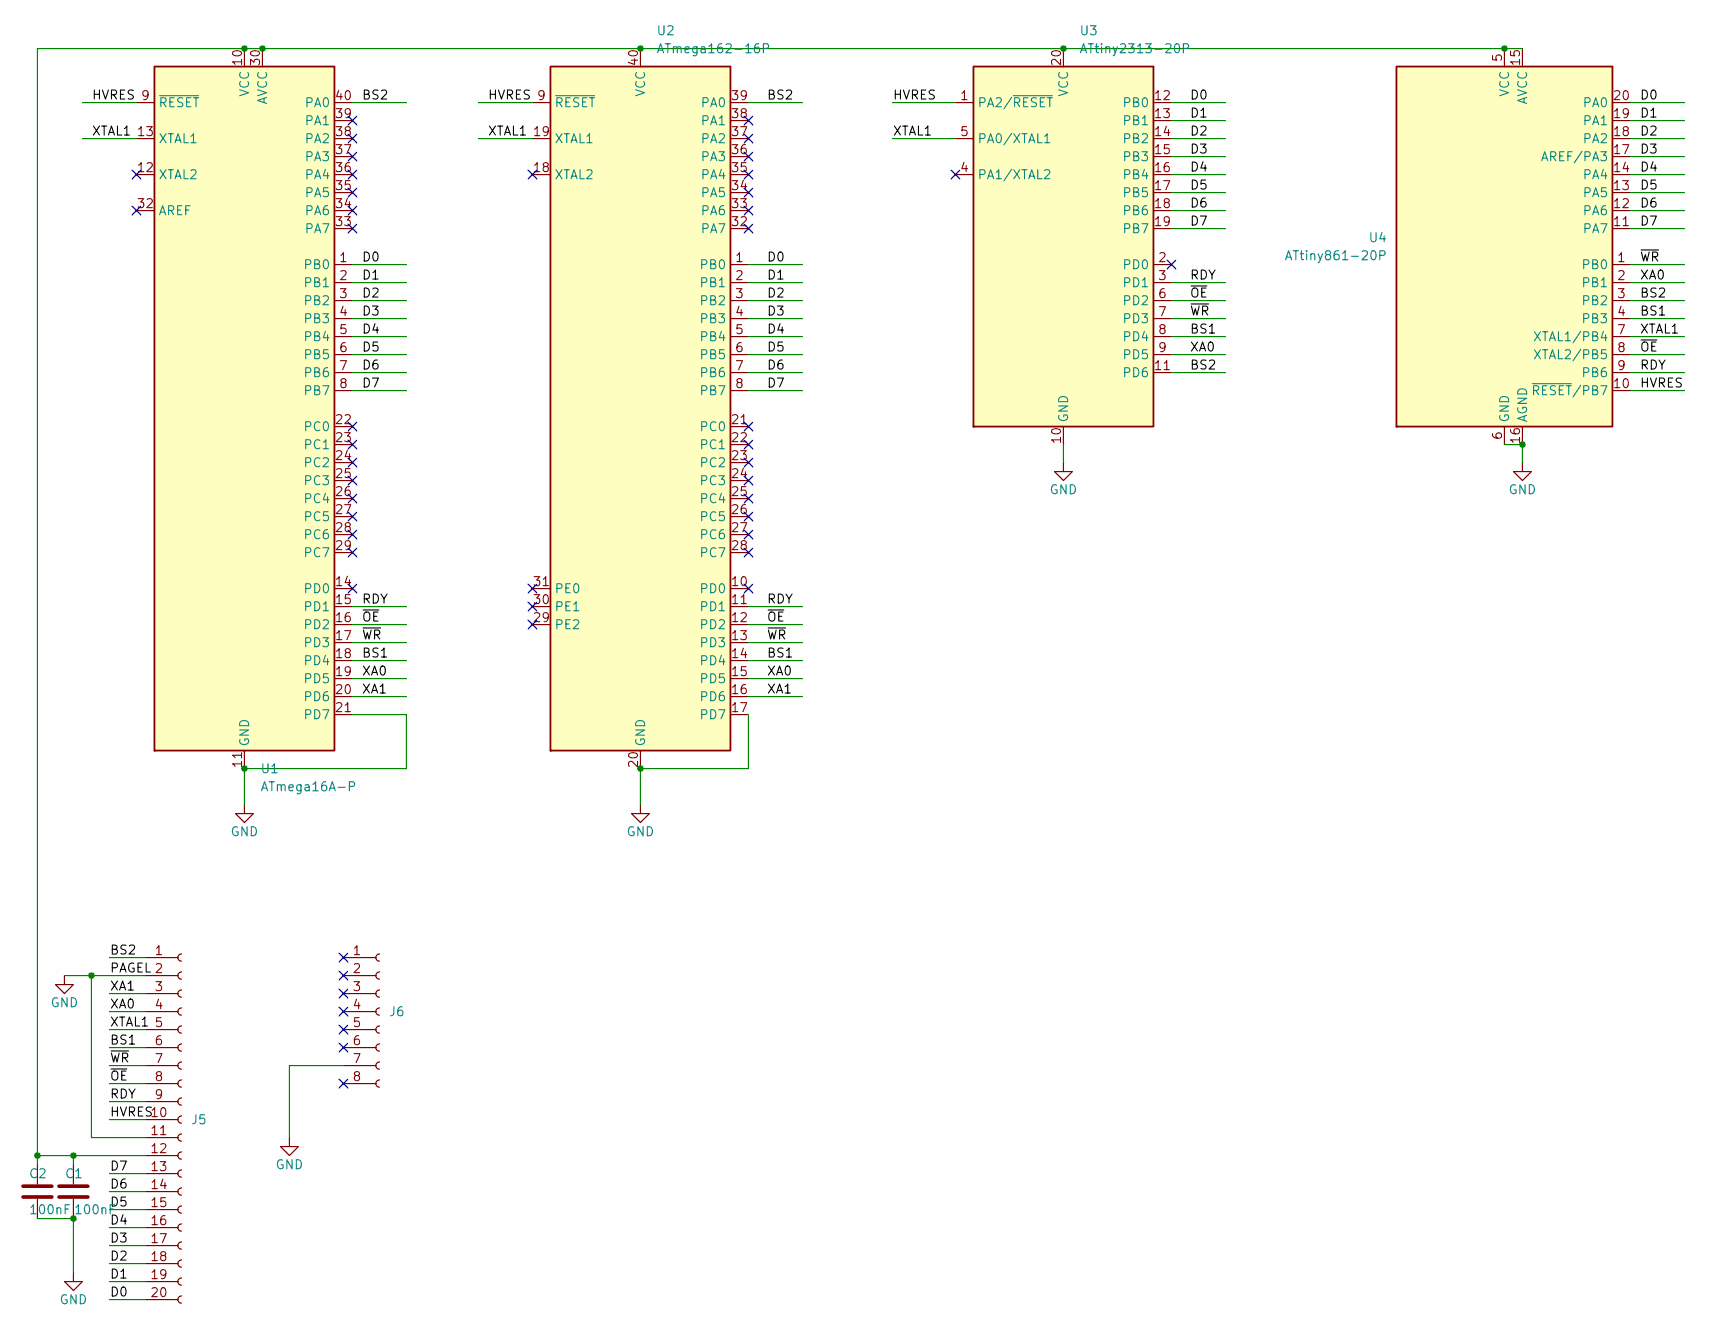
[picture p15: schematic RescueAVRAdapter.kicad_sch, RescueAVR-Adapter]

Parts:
C1, C2: 100nF; C_Disc_D7.5mm_W2.5mm_P5.00mm
J5: Conn_01x20_Socket; PinHeader_1x20_P2.54mm_Vertical
J6: Conn_01x08_Socket; PinHeader_1x08_P2.54mm_Vertical
U1: ATmega16A-P; DIP-40_W15.24mm_Socket
U2: ATmega162-16P; DIP-40_W15.24mm_Socket
U3: ATtiny2313-20P; DIP-20_W7.62mm_Socket
U4: ATtiny861-20P; DIP-20_W7.62mm_Socket

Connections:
/BS1: J5.6, U1.18 (PD4), U2.14 (PD4), U3.8 (PD4), U4.4 (PB3)
/BS2: J5.1, U1.40 (PA0), U2.39 (PA0), U3.11 (PD6), U4.3 (PB2)
/D0: J5.20, U1.1 (PB0), U2.1 (PB0), U3.12 (PB0), U4.20 (PA0)
/D1: J5.19, U1.2 (PB1), U2.2 (PB1), U3.13 (PB1), U4.19 (PA1)
/D2: J5.18, U1.3 (PB2), U2.3 (PB2), U3.14 (PB2), U4.18 (PA2)
/D3: J5.17, U1.4 (PB3), U2.4 (PB3), U3.15 (PB3), U4.17 (AREF/PA3)
/D4: J5.16, U1.5 (PB4), U2.5 (PB4), U3.16 (PB4), U4.14 (PA4)
/D5: J5.15, U1.6 (PB5), U2.6 (PB5), U3.17 (PB5), U4.13 (PA5)
/D6: J5.14, U1.7 (PB6), U2.7 (PB6), U3.18 (PB6), U4.12 (PA6)
/D7: J5.13, U1.8 (PB7), U2.8 (PB7), U3.19 (PB7), U4.11 (PA7)
/HVRES: J5.10, U1.9 (~RESET), U2.9 (~RESET), U3.1 (PA2/~RESET), U4.10 (~RESET/PB7)
/RDY: J5.9, U1.15 (PD1), U2.11 (PD1), U3.3 (PD1), U4.9 (PB6)
/XA0: J5.4, U1.19 (PD5), U2.15 (PD5), U3.9 (PD5), U4.2 (PB1)
/XA1: J5.3, U1.20 (PD6), U2.16 (PD6)
/XTAL1: J5.5, U1.13 (XTAL1), U2.19 (XTAL1), U3.5 (PA0/XTAL1), U4.7 (XTAL1/PB4)
/~OE: J5.8, U1.16 (PD2), U2.12 (PD2), U3.6 (PD2), U4.8 (XTAL2/PB5)
/~WR: J5.7, U1.17 (PD3), U2.13 (PD3), U3.7 (PD3), U4.1 (PB0)
GND: C1.2, C2.2, J5.2, J5.11, J6.7, U1.11 (GND), U1.21 (PD7), U1.31 (GND), U2.17 (PD7), U2.20 (GND), U3.10 (GND), U4.6 (GND), U4.16 (AGND)
unnamed: C1.1, C2.1, J5.12, U1.10 (VCC), U1.30 (AVCC), U2.40 (VCC), U3.20 (VCC), U4.5 (VCC), U4.15 (AVCC)

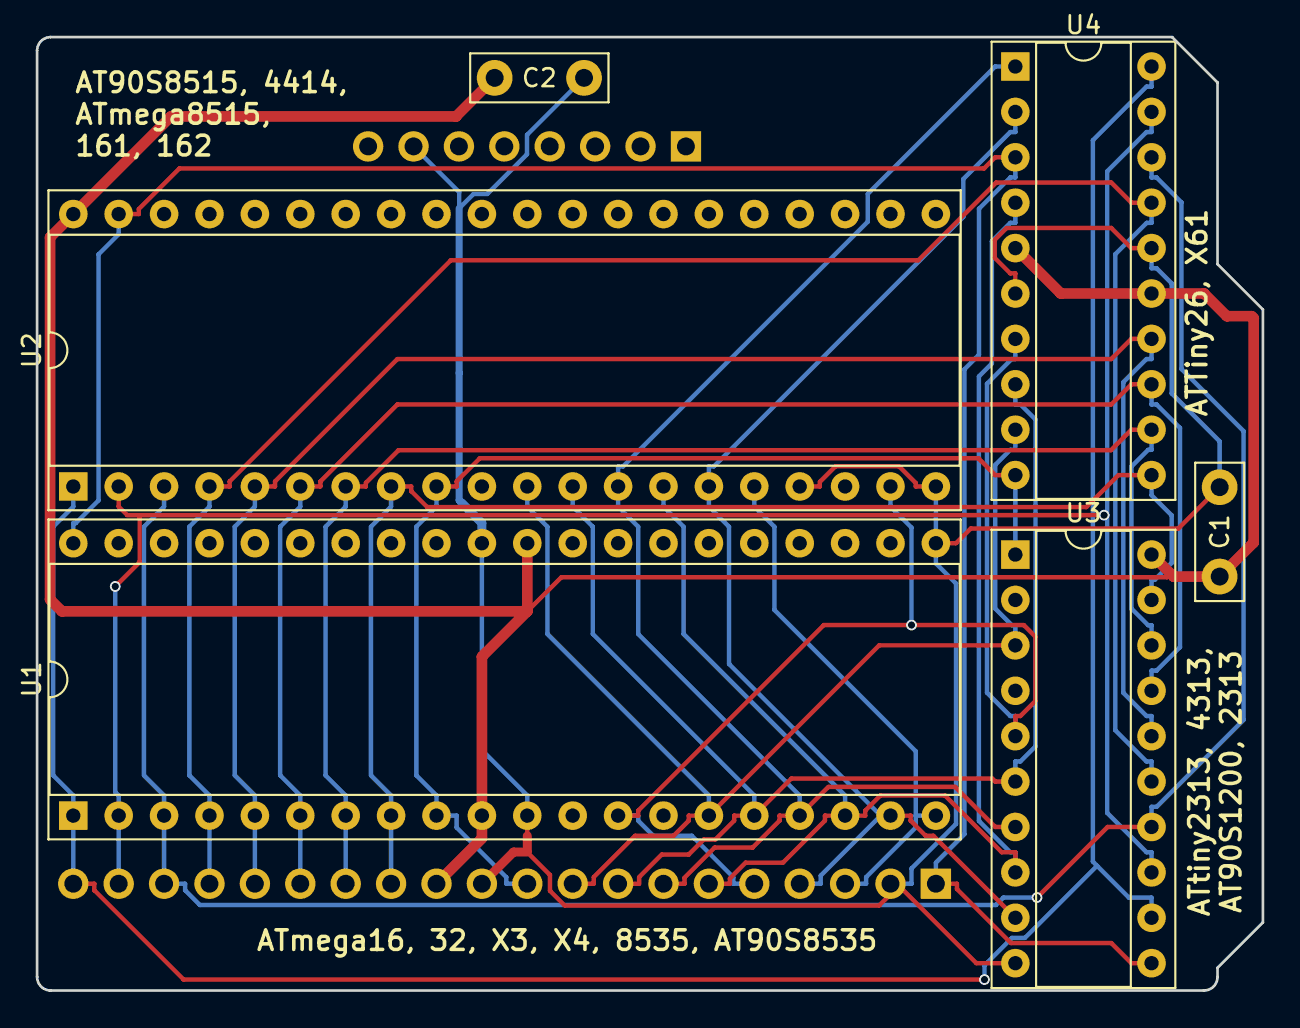
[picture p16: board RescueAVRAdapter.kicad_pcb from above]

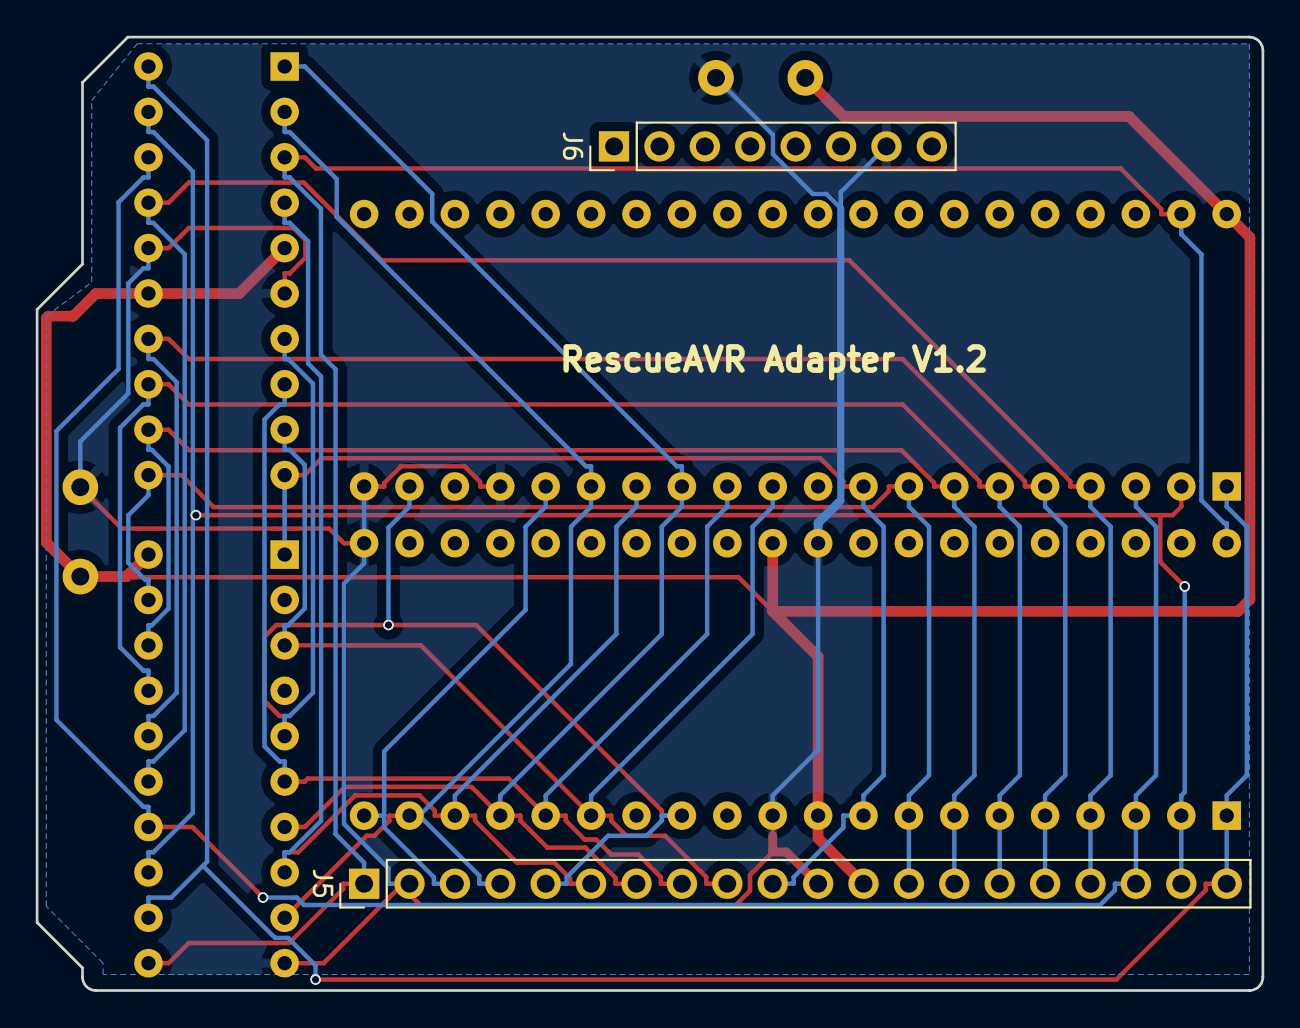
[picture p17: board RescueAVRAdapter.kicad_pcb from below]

Board: 2 copper layers, 68.6 x 53.3 mm, 8 parts (2 on the bottom side), 19 nets.

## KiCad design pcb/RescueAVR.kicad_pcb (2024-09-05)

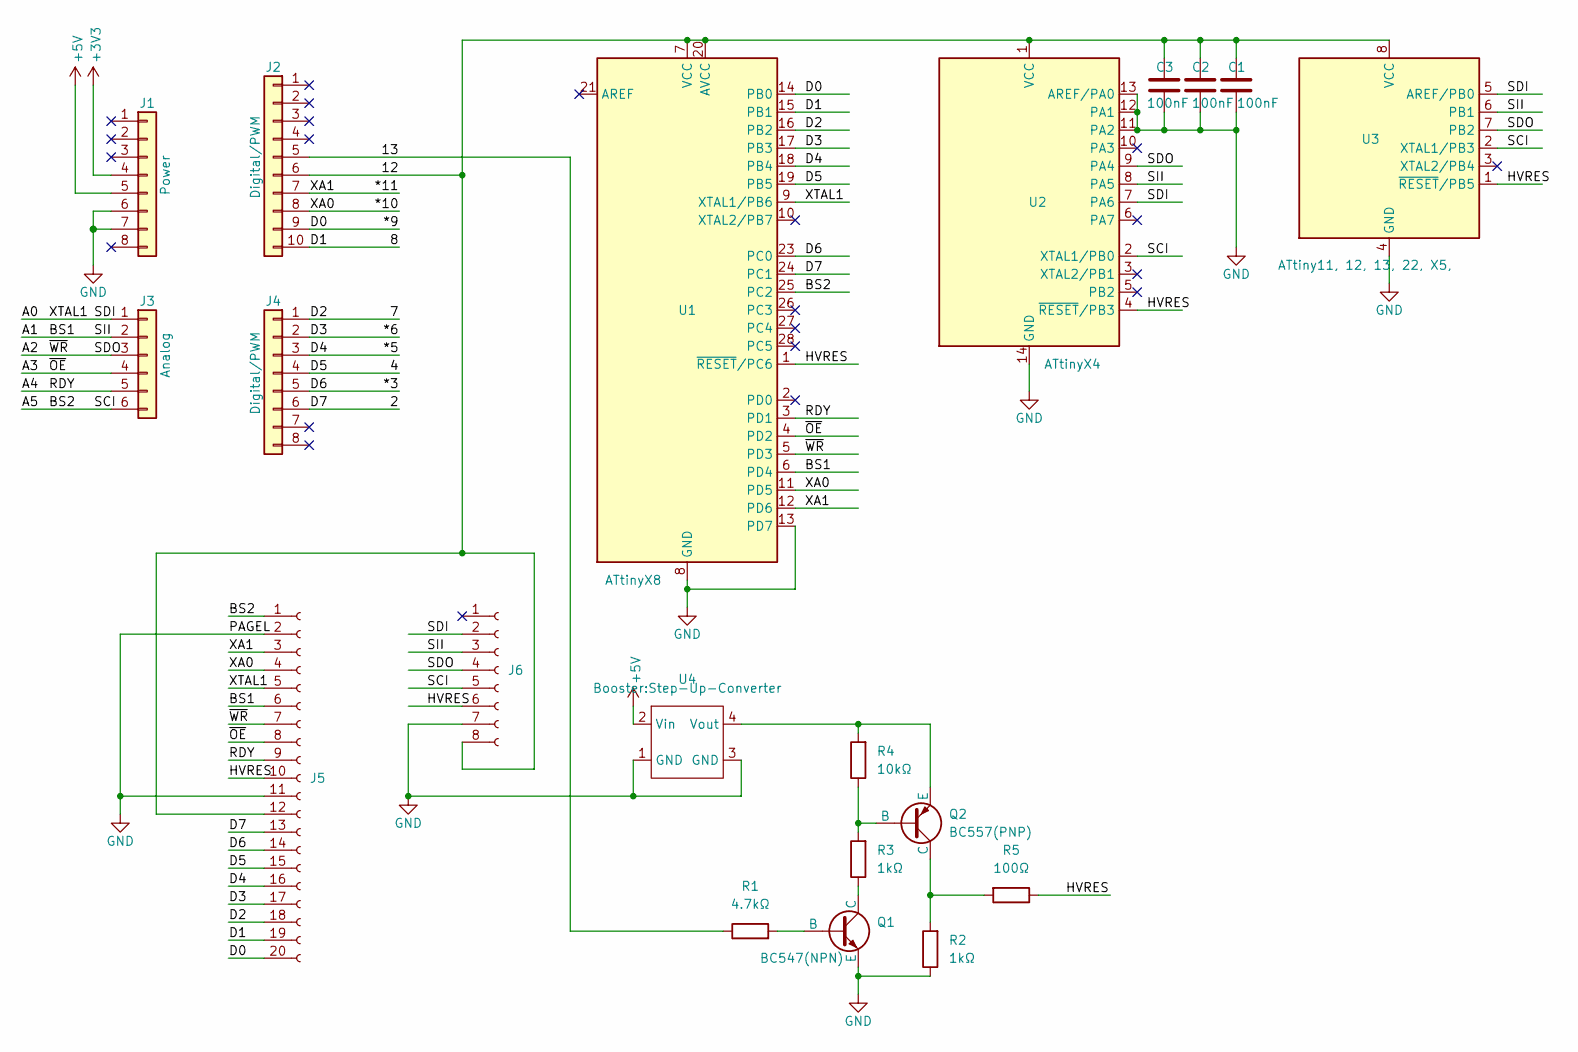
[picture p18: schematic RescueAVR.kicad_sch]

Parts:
C1, C2, C3: 100nF; C_Disc_D7.5mm_W2.5mm_P5.00mm
J1: Power; PinHeader_1x08_P2.54mm_Vertical
J2: Digital/PWM; PinHeader_1x10_P2.54mm_Vertical
J3: Analog; PinHeader_1x06_P2.54mm_Vertical
J4: Digital/PWM; PinHeader_1x08_P2.54mm_Vertical
J5: Conn_01x20_Socket; PinSocket_1x20_P2.54mm_Vertical
J6: Conn_01x08_Socket; PinSocket_1x08_P2.54mm_Vertical
Q1: BC547(NPN); TO-92
Q2: BC557(PNP); TO-92
R1: 4.7kΩ; R_Axial_DIN0204_L3.6mm_D1.6mm_P7.62mm_Horizontal
R2, R3: 1kΩ; R_Axial_DIN0204_L3.6mm_D1.6mm_P7.62mm_Horizontal
R4: 10kΩ; R_Axial_DIN0204_L3.6mm_D1.6mm_P7.62mm_Horizontal
R5: 100Ω; R_Axial_DIN0204_L3.6mm_D1.6mm_P7.62mm_Horizontal
U1: ATtinyX8; DIP-28_W7.62mm_Socket
U2: ATtinyX4; DIP-14_W7.62mm_Socket
U3: ATtiny11, 12, 13, 22, X5,; DIP-8_W7.62mm_Socket
U4: Step-Up-Converter

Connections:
+3V3: J1.4
+5V: J1.5, U4.2 (Vin)
/2: J4.6, J5.13, U1.24 (PC1)
/4: J4.4, J5.15, U1.19 (PB5)
/7: J4.1, J5.18, U1.16 (PB2)
/8: J2.10, J5.19, U1.15 (PB1)
/12: C1.1, C2.1, C3.1, J2.6, J5.12, J6.8, U1.7 (VCC), U1.20 (AVCC), U2.1 (VCC), U3.8 (VCC)
/13: J2.5, R1.1
/*3: J4.5, J5.14, U1.23 (PC0)
/*5: J4.3, J5.16, U1.18 (PB4)
/*6: J4.2, J5.17, U1.17 (PB3)
/*9: J2.9, J5.20, U1.14 (PB0)
/*10: J2.8, J5.4, U1.11 (PD5)
/*11: J2.7, J5.3, U1.12 (PD6)
/A0: J3.1, J5.5, J6.2, U1.9 (XTAL1/PB6), U2.7 (PA6), U3.5 (AREF/PB0)
/A1: J3.2, J5.6, J6.3, U1.6 (PD4), U2.8 (PA5), U3.6 (PB1)
/A2: J3.3, J5.7, J6.4, U1.5 (PD3), U2.9 (PA4), U3.7 (PB2)
/A3: J3.4, J5.8, U1.4 (PD2)
/A4: J3.5, J5.9, U1.3 (PD1)
/A5: J3.6, J5.1, J6.5, U1.25 (PC2), U2.2 (XTAL1/PB0), U3.2 (XTAL1/PB3)
/HVRES: J5.10, J6.6, R5.1, U1.1 (~RESET/PC6), U2.4 (~RESET/PB3), U3.1 (~RESET/PB5)
GND: C1.2, C2.2, C3.2, J1.6, J1.7, J5.2, J5.11, J6.7, Q1.3 (E), R2.1, U1.8 (GND), U1.13 (PD7), U1.22 (GND), U2.11 (PA2), U2.12 (PA1), U2.13 (AREF/PA0), U2.14 (GND), U3.4 (GND), U4.1 (GND), U4.3 (GND)
unnamed: Q1.2 (B), R1.2
unnamed: Q1.1 (C), R3.1
unnamed: Q2.2 (B), R3.2, R4.1
unnamed: Q2.1 (C), R2.2, R5.2
unnamed: Q2.3 (E), R4.2, U4.4 (Vout)

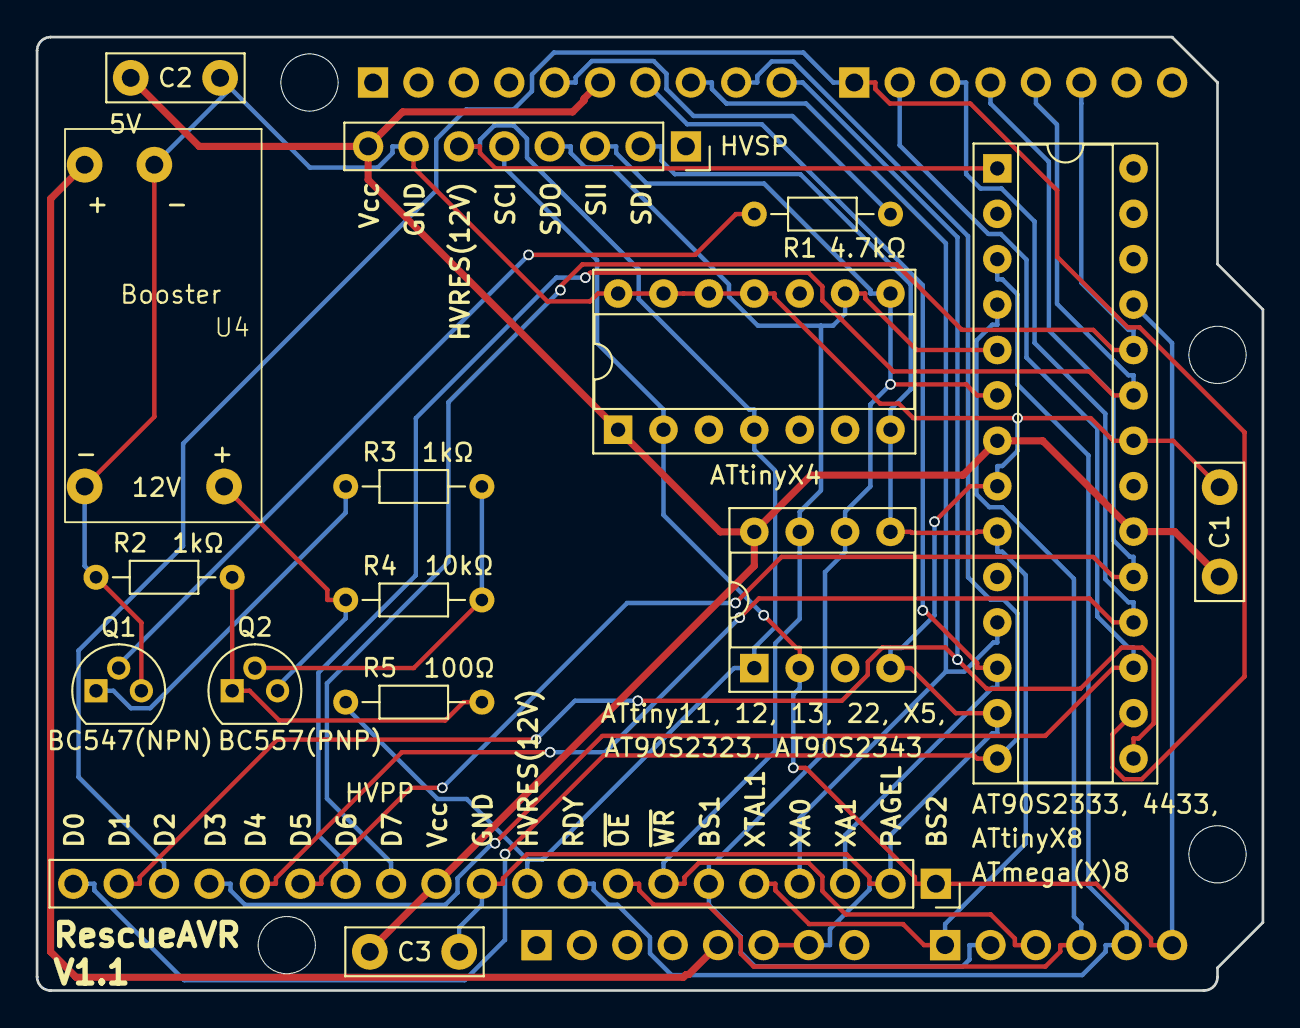
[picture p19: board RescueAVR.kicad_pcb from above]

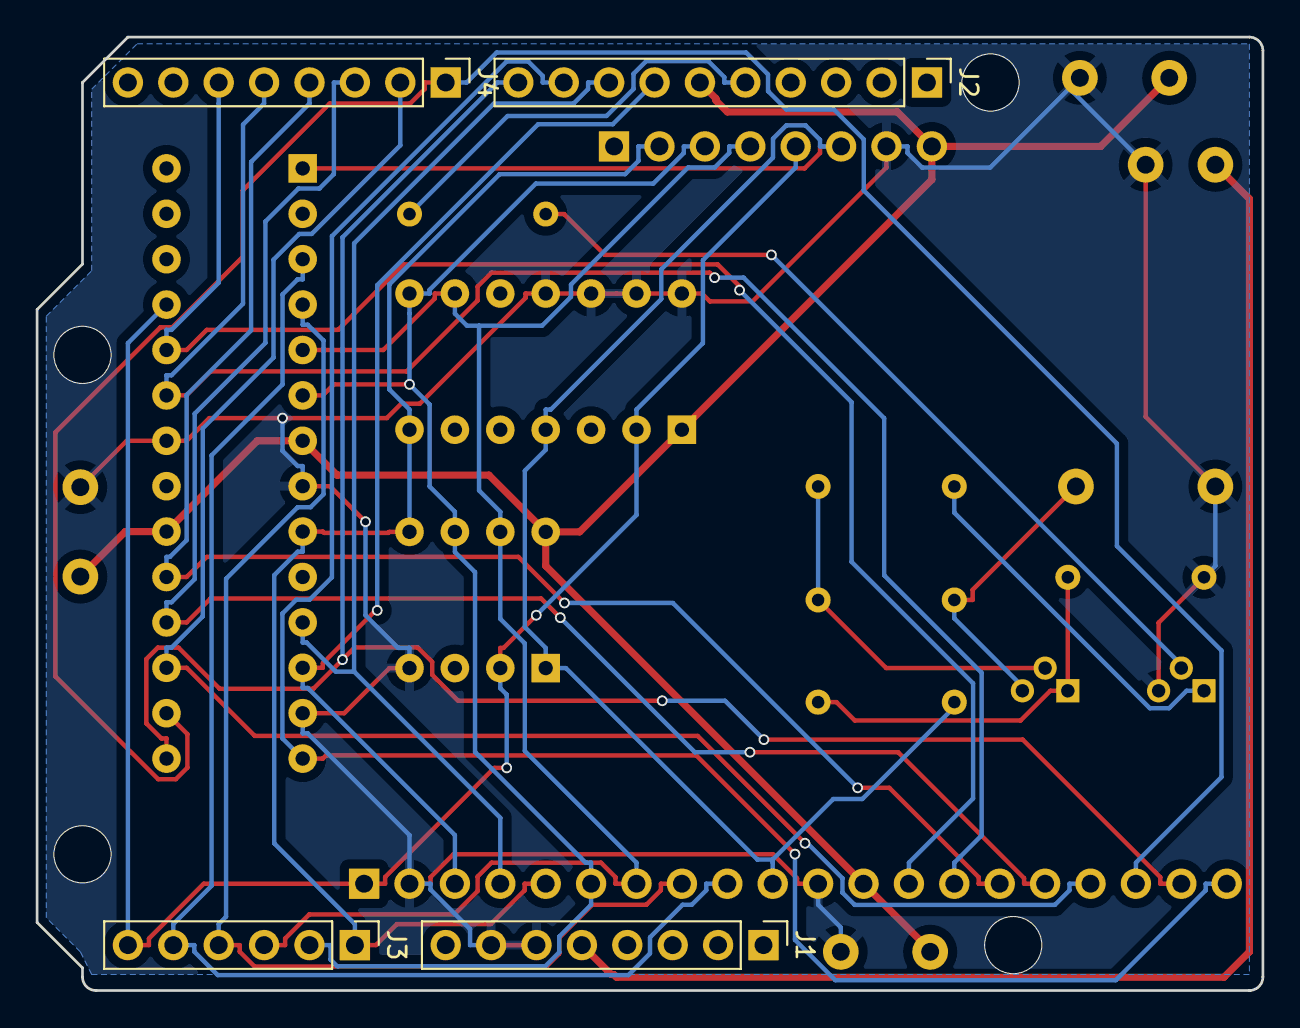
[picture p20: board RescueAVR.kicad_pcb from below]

Board: 2 copper layers, 68.6 x 53.3 mm, 24 parts (4 on the bottom side), 26 nets.

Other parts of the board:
MH1, MH2, MH3, MH4: MountingHole_3.2mm

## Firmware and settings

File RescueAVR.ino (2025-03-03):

// -*- mode: c++; tab-width: 4; indent-tabs-mode: nil -*-

//  Title:        RescueAVR

#define VERSION  "3.1.1"

/*Copyright 2013-2021 by Bernhard Nebel and parts are copyrighted by Jeff Keyzer.
  License: GPLv3

  It uses the hardware designed by manekinen, but the software is completely
  new, using ideas und snippets from  Jeff Keyzer's sketch HVRescue_Shield.
  In addition, the program can also be run on an Arduino Uno, Nano, or Pro.

  The program can be either compiled for Arduino Uno, Nano, or Pro, Mega, or Leonardo, 
  or for Fusebit Doctor boards (in all other cases). If you want to compile it for the
  Fusebit Doctor board, I recommend to use the MiniCore.
 
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
Version 2.3 (21.1.2021)
  - added: support for ATtiny1634
  - fixed: corrected the code for reading the OSCCAL value
  - added: 'R - Restart' mow in all menus 
  - changed: resurrect to 'T')

Version 2.3.1 (25.1.2022)
  - added: some explanantion
  - changed: made compile mode dependend on target board specification 
  - fixed a few warnings
  - added: Github actions

Version 2.4.0 (20.8.2024)
  - added a few MCUs: ATtiny22, ATtiny43U, ATtiny87, ATtiny167, ATmega48PB, 
    ATmega88PB, ATmega168PB, ATmega328PB,
    ATmega640, ATmega1280, ATmega1281, ATmega2560, ATmega2561, ATmega8U2, ATmega16U2, 
    ATmega32U2, ATmega16U4, ATmega32U4,
    AT90S2333, ATtiny441, ATtiny841, ATtiny828
  - renamed: ATMEGA -> HVPP and TINY2313 -> TINYHVPP
  - added: ARDUINO_AVR_PRO is now in the list of boards that can execute 
    the Arduino version of the RescueAVR sketch 

Version 2.5.0 (28.8.2024)
  - fixed: handling of MCUs that read lock and fuse bits into one byte 
    (some of the very obsolete MCUs). These have now a marker in the number of
    of fuse bytes field at bit 7 in the MCU table.
  - fixed: use direct printing of MCU name in printMCUName instead of going via
    a buffer (which was too small and led to a buffer overrun)
  - fixed: for ATTiny11, ATtiny12, compare only the LB1 and LB2 bits of the 
    lock byte when verifying after resurrection!
  - fixed: give error message when selecting 'H' or 'X' and there are not enough fuse bytes
  - added: all missing currently supported MCUs after running extract.py on the ATDF files
  - added: a few more obsolete MCUs, e.g., AT90S1200, ATmega161, ...
  - added: restart option when asking for number of fuse bytes
  - removed: attempting to clear lock bits because this always fails! 

Version 2.6.0 (18.8.2024)
  - fixed: handling of MCUs that read fuse and lock bits in one byte (AT90S2323 etc.)
  - fixed: ATtiny11 & 12 handling 

Version 2.7.0 (8.9.2024)
  - added Arduino Mega as a possible host platform

Version 3.0.0 (9.9.2024)
  - changed: program logic does not require software resets any longer
  - changed: "setting xxx fuse" -> "new xxx fuse value"
  - added: when using the Arduino monitor window, you can now write the new byte value
    immediately after the command character
  - added: Leonardo as host board
  - fixed: questions for fuse bytes does now appear only once

Version 3.0.1 (9.9.2024)
  - changed: request to 'restart' instead of 'reset' 

Version 3.0.2 (10.9.2024)
  - fixed: for AT90S8515 and AT90S2313, it seems necessary to use multiple attempts to write the lock byte
  - fixed: for the AT90S chips, longer WR pulses are necessary for trhe erase function 

Version 3.1.0 (28.9.2024)
  - added: New mcu mode, called SLOWHVSP ("HVSP for Tiny15"), 
    where 16 clock pulses are generated instead of one
  - fixed: HV programming now works for ATtiny15 as well (on a bread board) 
  - added: tested on AT90S4433

Version 3.3.1 (3.3.2025)
  - added a bit more text in the beginning
  - removed the 2 sec delay in the beginning. This was probably there because now after uploading the     firmware, you get some garbage output. 
*/



/* Uncomment one of the following two lines, if you do not want to
   leave the decision on which board the sketch is executed to the
   specification of the target board
*/
// #define FBD_MODE
// #define ARDUINO_MODE
//#ifdef ARDUINO_AVR_LEONARDO
//   #error "Arduino Leonardo is not supported"
//#endif

#if !defined(FBD_MODE) && !defined(ARDUINO_MODE)
  #if !defined(ARDUINO_AVR_UNO) && !defined(ARDUINO_AVR_NANO) && !defined(ARDUINO_AVR_PRO) && \
    !defined(ARDUINO_AVR_MEGA) && !defined(ARDUINO_AVR_MEGA2560) && !defined(ARDUINO_AVR_LEONARDO) && \
    !defined(ARDUINO_SAMD_ZERO)
    #define FBD_MODE
  #else
    #define ARDUINO_MODE
  #endif
#endif


#include <avr/pgmspace.h>

// communication speed 
#define  BAUD         19200    // Serial port rate at which to talk to PC


// Names of a few obsolete MCUs supporting HV prog
const char at90pwm2[] PROGMEM = "AT90PWM2/3";
const char at90s1200[] PROGMEM = "AT90S1200";
const char at90s2313[] PROGMEM = "AT90S2313";
const char at90s2323[] PROGMEM = "AT90S2323";
const char at90s2333[] PROGMEM = "AT90S2333";
const char at90s2343[] PROGMEM = "AT90S2343";
const char at90s4414[] PROGMEM = "AT90S4414";
const char at90s4433[] PROGMEM = "AT90S4433";
const char at90s4434[] PROGMEM = "AT90S4434";
const char at90s8515[] PROGMEM = "AT90S8515";
const char at90s8535[] PROGMEM = "AT90S8535";
const char atmega103[] PROGMEM = "ATmega103";
const char atmega161[] PROGMEM = "ATmega161";
const char atmega163[] PROGMEM = "ATmega163";
const char atmega323[] PROGMEM = "ATmega323";
const char attiny22[] PROGMEM = "ATtiny22";
const char attiny28[] PROGMEM = "ATtiny28";

// Names of supported MCUs as extracted by extract.py
// Do not change manually!
const char at90can128[] PROGMEM = "AT90CAN128";
const char at90can32[] PROGMEM = "AT90CAN32";
const char at90can64[] PROGMEM = "AT90CAN64";
const char at90pwm1[] PROGMEM = "AT90PWM1/AT90PWM2B/AT90PWM3B";
const char at90pwm161[] PROGMEM = "AT90PWM161";
const char at90pwm216[] PROGMEM = "AT90PWM216/AT90PWM316";
const char at90pwm81[] PROGMEM = "AT90PWM81";
const char at90usb1286[] PROGMEM = "AT90USB1286/AT90USB1287";
const char at90usb162[] PROGMEM = "AT90USB162";
const char at90usb646[] PROGMEM = "AT90USB646/AT90USB647";
const char at90usb82[] PROGMEM = "AT90USB82";
const char atmega128[] PROGMEM = "ATmega128/ATmega128A";
const char atmega1280[] PROGMEM = "ATmega1280";
const char atmega1281[] PROGMEM = "ATmega1281";
const char atmega1284[] PROGMEM = "ATmega1284";
const char atmega1284p[] PROGMEM = "ATmega1284P";
const char atmega1284rfr2[] PROGMEM = "ATmega1284RFR2";
const char atmega128rfa1[] PROGMEM = "ATmega128RFA1";
const char atmega128rfr2[] PROGMEM = "ATmega128RFR2";
const char atmega16[] PROGMEM = "ATmega16/ATmega16A";
const char atmega162[] PROGMEM = "ATmega162";
const char atmega164a[] PROGMEM = "ATmega164A";
const char atmega164p[] PROGMEM = "ATmega164P/ATmega164PA";
const char atmega165a[] PROGMEM = "ATmega165A";
const char atmega165p[] PROGMEM = "ATmega165P/ATmega165PA";
const char atmega168[] PROGMEM = "ATmega168/ATmega168A";
const char atmega168p[] PROGMEM = "ATmega168P/ATmega168PA";
const char atmega168pb[] PROGMEM = "ATmega168PB";
const char atmega169a[] PROGMEM = "ATmega169A";
const char atmega169p[] PROGMEM = "ATmega169P/ATmega169PA";
const char atmega16hva[] PROGMEM = "ATmega16HVA";
const char atmega16hvb[] PROGMEM = "ATmega16HVB/ATmega16HVBrevB";
const char atmega16m1[] PROGMEM = "ATmega16M1";
const char atmega16u2[] PROGMEM = "ATmega16U2";
const char atmega16u4[] PROGMEM = "ATmega16U4";
const char atmega2560[] PROGMEM = "ATmega2560";
const char atmega2561[] PROGMEM = "ATmega2561";
const char atmega2564rfr2[] PROGMEM = "ATmega2564RFR2";
const char atmega256rfr2[] PROGMEM = "ATmega256RFR2";
const char atmega32[] PROGMEM = "ATmega32/ATmega32A";
const char atmega324a[] PROGMEM = "ATmega324A";
const char atmega324p[] PROGMEM = "ATmega324P";
const char atmega324pa[] PROGMEM = "ATmega324PA";
const char atmega324pb[] PROGMEM = "ATmega324PB";
const char atmega325[] PROGMEM = "ATmega325/ATmega325A";
const char atmega3250[] PROGMEM = "ATmega3250/ATmega3250A";
const char atmega3250p[] PROGMEM = "ATmega3250P/ATmega3250PA";
const char atmega325p[] PROGMEM = "ATmega325P/ATmega325PA";
const char atmega328[] PROGMEM = "ATmega328";
const char atmega328p[] PROGMEM = "ATmega328P";
const char atmega328pb[] PROGMEM = "ATmega328PB";
const char atmega329[] PROGMEM = "ATmega329/ATmega329A";
const char atmega3290[] PROGMEM = "ATmega3290/ATmega3290A";
const char atmega3290p[] PROGMEM = "ATmega3290P/ATmega3290PA";
const char atmega329p[] PROGMEM = "ATmega329P/ATmega329PA";
const char atmega32c1[] PROGMEM = "ATmega32C1";
const char atmega32hvb[] PROGMEM = "ATmega32HVB/ATmega32HVBrevB";
const char atmega32m1[] PROGMEM = "ATmega32M1";
const char atmega32u2[] PROGMEM = "ATmega32U2";
const char atmega32u4[] PROGMEM = "ATmega32U4";
const char atmega406[] PROGMEM = "ATmega406";
const char atmega48[] PROGMEM = "ATmega48/ATmega48A";
const char atmega48p[] PROGMEM = "ATmega48P/ATmega48PA";
const char atmega48pb[] PROGMEM = "ATmega48PB";
const char atmega64[] PROGMEM = "ATmega64/ATmega64A";
const char atmega640[] PROGMEM = "ATmega640";
const char atmega644[] PROGMEM = "ATmega644/ATmega644A";
const char atmega644p[] PROGMEM = "ATmega644P/ATmega644PA";
const char atmega644rfr2[] PROGMEM = "ATmega644RFR2";
const char atmega645[] PROGMEM = "ATmega645/ATmega645A";
const char atmega6450[] PROGMEM = "ATmega6450/ATmega6450A";
const char atmega6450p[] PROGMEM = "ATmega6450P";
const char atmega645p[] PROGMEM = "ATmega645P";
const char atmega649[] PROGMEM = "ATmega649/ATmega649A";
const char atmega6490[] PROGMEM = "ATmega6490/ATmega6490A";
const char atmega6490p[] PROGMEM = "ATmega6490P";
const char atmega649p[] PROGMEM = "ATmega649P";
const char atmega64c1[] PROGMEM = "ATmega64C1";
const char atmega64hve2[] PROGMEM = "ATmega64HVE2";
const char atmega64m1[] PROGMEM = "ATmega64M1";
const char atmega64rfr2[] PROGMEM = "ATmega64RFR2";
const char atmega8[] PROGMEM = "ATmega8/ATmega8A";
const char atmega8515[] PROGMEM = "ATmega8515";
const char atmega8535[] PROGMEM = "ATmega8535";
const char atmega88[] PROGMEM = "ATmega88/ATmega88A";
const char atmega88p[] PROGMEM = "ATmega88P/ATmega88PA";
const char atmega88pb[] PROGMEM = "ATmega88PB";
const char atmega8hva[] PROGMEM = "ATmega8HVA";
const char atmega8u2[] PROGMEM = "ATmega8U2";
const char attiny11[] PROGMEM = "ATtiny11";
const char attiny12[] PROGMEM = "ATtiny12";
const char attiny13[] PROGMEM = "ATtiny13/ATtiny13A";
const char attiny15[] PROGMEM = "ATtiny15";
const char attiny1634[] PROGMEM = "ATtiny1634";
const char attiny167[] PROGMEM = "ATtiny167";
const char attiny2313[] PROGMEM = "ATtiny2313/ATtiny2313A";
const char attiny24[] PROGMEM = "ATtiny24/ATtiny24A";
const char attiny25[] PROGMEM = "ATtiny25";
const char attiny26[] PROGMEM = "ATtiny26";
const char attiny261[] PROGMEM = "ATtiny261/ATtiny261A";
const char attiny4313[] PROGMEM = "ATtiny4313";
const char attiny43u[] PROGMEM = "ATtiny43U";
const char attiny44[] PROGMEM = "ATtiny44/ATtiny44A";
const char attiny441[] PROGMEM = "ATtiny441";
const char attiny45[] PROGMEM = "ATtiny45";
const char attiny461[] PROGMEM = "ATtiny461/ATtiny461A";
const char attiny48[] PROGMEM = "ATtiny48";
const char attiny828[] PROGMEM = "ATtiny828";
const char attiny84[] PROGMEM = "ATtiny84/ATtiny84A";
const char attiny841[] PROGMEM = "ATtiny841";
const char attiny85[] PROGMEM = "ATtiny85";
const char attiny861[] PROGMEM = "ATtiny861/ATtiny861A";
const char attiny87[] PROGMEM = "ATtiny87";
const char attiny88[] PROGMEM = "ATtiny88";



// table with signatures
// 1st word signature (w/o 1E),
// 2nd word: MSB: bit7=read lock byte for lock+fuses
//                bit0-bit3=number of fuses
// 2nd word LSB: low fuse,
// 3rd word MSB: high fuse,
// 3rd word LSB: extended fuse,
// 4th word: string address for MCU name
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
void loop() {  // run over and over again
  
  byte hfuse = 0, lfuse = 0, efuse = 0, lock = 0, osccal = 0;  // fuse and lock values
  byte dhfuse = 0, dlfuse = 0, defuse = 0;  // default values
  char action = ' ';

  while (!startup());
  
  if (mcu_index >= 0) {
    dlfuse = pgm_read_word(&(mcu_types[mcu_index][1]))&0xFF;
    dhfuse = pgm_read_word(&(mcu_types[mcu_index][2]))>>8;
    defuse = pgm_read_word(&(mcu_types[mcu_index][2]))&0xFF;
  }

  enterHVProgMode(mcu_mode);
  

  lfuse = readFuse(mcu_mode,LFUSE_SEL,fuse_and_lock);
  if (mcu_fuses > 1)
    hfuse = readFuse(mcu_mode,HFUSE_SEL,fuse_and_lock);
  if (mcu_fuses > 2)
    efuse = readFuse(mcu_mode,EFUSE_SEL,fuse_and_lock);
  lock = readFuse(mcu_mode,LOCK_SEL,fuse_and_lock);
  osccal = readOSCCAL(mcu_mode);
  leaveHVProgMode(mcu_mode);

  printFuses("Current ",mcu_fuses,lfuse,hfuse,efuse);
  if (mcu_index >= 0) printFuses("Default ",mcu_fuses,dlfuse,dhfuse,defuse);

  printLock(lock);
  printOSCCAL(osccal);
 

  if (interactive_mode) {
    while (true) {
      while (Serial.available()) Serial.read();
      Serial.println();
      Serial.println(F("Choose:"));
      if (mcu_index >= 0) Serial.println(F("  T - Try to resurrect chip by all means"));
      Serial.println(F("  E - Erase chip"));
      if (mcu_index >= 0) Serial.println(F("  D - Burn default fuse values"));
      Serial.println(F("  L - Change low fuse"));
      if (mcu_fuses > 1) Serial.println(F("  H - Change high fuse"));
      if (mcu_fuses > 2) Serial.println(F("  X - Change extended fuse"));
      Serial.println(F("  K - Change lock byte"));
      Serial.println(F("  R - Restart"));
      Serial.print(F("Action: "));
      
      while (!Serial.available()) { };
      action = toupper(Serial.read());
      Serial.println(action);
      
      if (action == 'E' || action == 'D' || action == 'L' ||
          (action == 'H' && mcu_fuses > 1) ||
          (action == 'X' && mcu_fuses > 2) ||
          action == 'K' || action == 'T' || action == 'R') break;
      if (action >= ' ') {
        Serial.print("'");
        Serial.print(action);
        Serial.println("' is not a valid command char.");
      }
    }
  
    enterHVProgMode(mcu_mode);
    switch (action) {
    case 'R':
      return;
      break;
    case 'T':
      if (mcu_index >= 0) resurrection(dlfuse, dhfuse, defuse);
      break;
    case 'E': 
#ifdef FBD_MODE
      ec_allowed = (digitalRead(ECJUMPER) == LOW);
#endif
      if (ec_allowed) {
        Serial.print(F("\nErasing chip ..."));
        eraseChip(mcu_mode); 
        verifyOneByte(LOCK_SEL, 0xFF, "erasing chip");
      }
      else Serial.println(F("'Erase chip' is not allowed"));
      break;
    case 'D': 
      if (mcu_index >= 0) {
        Serial.print(F("\nSetting fuses ... "));
        burnFuse(mcu_mode, dlfuse, LFUSE_SEL);
        if (mcu_fuses > 1) burnFuse(mcu_mode, dhfuse, HFUSE_SEL);
        if (mcu_fuses > 2) burnFuse(mcu_mode, defuse, EFUSE_SEL);
        showLed(true,true,600);
        Serial.println(F("done"));
        delay(100);
        Serial.print(F("Verifying ... "));
        lfuse = readFuse(mcu_mode,LFUSE_SEL,fuse_and_lock);
        if (mcu_fuses > 1) hfuse = readFuse(mcu_mode,HFUSE_SEL,fuse_and_lock);
        if (mcu_fuses > 2) efuse = readFuse(mcu_mode,EFUSE_SEL,fuse_and_lock);
        showLed(true,true,600);
        if (verifyFuses(mcu_fuses,
                        0xFF,0xFF,
                        lfuse,dlfuse,
                        hfuse,dhfuse,
                        efuse,defuse)) {
          Serial.println(F("done: Sucessfully set all fuses to default values"));
        } else {
          Serial.println(F("done: FAILED TO SET FUSES\x07"));
        }
      }
      break;
    case 'L': setAndVerifyOneByte(LFUSE_SEL, "low fuse value");
      break;
    case 'H': 
      if (mcu_fuses > 1) {
        setAndVerifyOneByte(HFUSE_SEL, "high fuse value");
      }
      break;
    case 'X':
      if (mcu_fuses > 2) {
        setAndVerifyOneByte(EFUSE_SEL, "extended fuse value");
      }
      break;
    case 'K':
      setAndVerifyOneByte(LOCK_SEL, "lock byte");
      break;
    }
    Serial.println();
    leaveHVProgMode(mcu_mode);
  } else { // non-interactive mode
    resurrection(dlfuse, dhfuse, defuse);
    Serial.println(F("Bye, bye ..."));
    while (true) { };
  }
}

void resurrection(byte dlf, byte dhf, byte def) {
  byte lf = 0, hf = 0, ef = 0, lk = 0;
  
  Serial.println(F("Start HV programming mode..."));
  enterHVProgMode(mcu_mode);
  showLed(true,true,400);
  
  // remove lock by erasing chip - if necessary and allowed
  lk = readFuse(mcu_mode, LOCK_SEL,fuse_and_lock);
#ifdef FBD_MODE
  ec_allowed = (digitalRead(ECJUMPER) == LOW);
#endif
  if (ec_allowed &&
      (lk != 0xFF &&
       (mcu_signature != 0x1E9005) &&  // if not ATtiny12, 
       (mcu_signature != 0x1E9004)) ||  // and not ATTiny11
      ((lk&0x06 ) != 0x06)) {
    Serial.println(F("Lock byte needs to be cleared. Erase chip ..."));
    eraseChip(mcu_mode); 
    showLed(true,true,400);
  }
  // try to reset fuses
  Serial.println(F("Set fuses to default values ..."));
  burnFuse(mcu_mode, dlf, LFUSE_SEL);
  if (mcu_fuses > 1) burnFuse(mcu_mode, dhf, HFUSE_SEL);
  if (mcu_fuses > 2) burnFuse(mcu_mode, def, EFUSE_SEL);
  showLed(true,true,400);
  
  // see whether successful
  lk = readFuse(mcu_mode, LOCK_SEL,fuse_and_lock);
  lf = readFuse(mcu_mode,LFUSE_SEL,fuse_and_lock);
  if (mcu_fuses > 1) hf = readFuse(mcu_mode,HFUSE_SEL,fuse_and_lock);
  if (mcu_fuses > 2) ef = readFuse(mcu_mode,EFUSE_SEL,fuse_and_lock);
  
  leaveHVProgMode(mcu_mode);
  // if successful blink green, otherwise blink red
  Serial.println(F("Verify fuse settings..."));
  showLed(true,false,100);
  showLed(false,true,100);
  showLed(true,false,100);
  showLed(false,true,100);
  showLed(true,false,100);
  showLed(false,true,100);
  if (verifyFuses(mcu_fuses,
                  lk,0xFF,
                  lf,dlf,
                  hf,dhf,
                  ef,def) ||
      (((mcu_signature == 0x1E9005) || // if ATtiny12, 
        (mcu_signature == 0x1E9004)) &&  // or ATTiny11
       ((lk&0x06 ) == 0x06) && // if LB1 & LB2 are unprogrammed 
       verifyFuses(mcu_fuses,
                   0xFF,0xFF,
                   lf,dlf,
                   hf,dhf,
                   ef,def))) {
    Serial.println(F("-> Resurrection was successful!"));
    ledBlink(GREEN,5);
  } else {
    Serial.println(F("-> Resurrection FAILED!"));
    if (!ec_allowed) 
      Serial.println(F("Try again with 'erase chip' jumper set"));
    ledBlink(RED,5);
  }
}


void setAndVerifyOneByte(int SEL, const char* mess) {
  int toburn;
  char testchar;
  boolean directbyte = false;

  if (Serial.available()) {
    testchar = toupper(Serial.peek());
    if ((testchar >= '0' && testchar <= '9') || (testchar >= 'A' && testchar <= 'F'))
      directbyte = true;
  }
  if (!directbyte) {
    while (Serial.available()) Serial.read();
  }
  Serial.print(F("New "));
  Serial.print(mess);
  Serial.print(F(": "));
  toburn = askByte();
  if (toburn >= 0x00) {
    Serial.print(F("\nSetting "));
    Serial.print(mess);
    Serial.print(F(" ... "));
    burnFuse(mcu_mode, toburn, SEL);
    verifyOneByte(SEL, toburn, mess);
  }
}

void verifyOneByte(int SEL, byte desired, const char* mess) {
  byte newval;

  showLed(true,true,600);
  Serial.println(F(" done"));
  delay(200);
  Serial.print(F("Verifying ... "));
  newval = readFuse(mcu_mode,SEL,fuse_and_lock);
  showLed(true,true,600);
  if (newval == desired) {
    Serial.print(F("done: Successful in "));
  } else {
    Serial.print(F("done: FAILED in \x07"));
  }
  Serial.println(mess);
}
  


int searchMCU(unsigned long sig) {
  if ((sig>>16) != 0x1E) return -1;
  for (int i=0; i < MCU_NUM; i++) {
    if ((sig&0xFFFF) == pgm_read_word(&(mcu_types[i][0])))
      return i;
  }
  return -1;
}

void printMCUName(int ix) {
  Serial.print((const __FlashStringHelper *)  pgm_read_word(&mcu_types[ix][3]));
}

void printHVLine(void) {
  Serial.print(F("HV type:   "));
  switch (mcu_mode) {
  case HVPP: Serial.println(F("HVPP")); break;
  case TINYHVPP: Serial.println(F("HVPP for Tiny")); break;
  case HVSP: Serial.println(F("HVSP")); break;
  case SLOWHVSP: Serial.println(F("HVSP for Tiny15")); break;
  default: Serial.println(F("Unknown")); break;
  }
}

boolean verifyFuses(int num, byte k1, byte k2, byte l1, byte l2, byte h1, byte h2, byte e1, byte e2) {
  boolean correct;
  correct = (k1 == k2);
  correct = (correct && (l1 == l2));
  if (num > 1) correct = (correct && (h1 == h2));
  if (num > 2) correct = (correct && (e1 == e2));
  return correct;
}

unsigned long readSig(int mode) {
  if (mode == HVSP || mode == SLOWHVSP) return readHVSPSig(mode);
  else return readHVPPSig(mode);
}
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

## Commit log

2013-10-01 Version 0.93 - a few correction & reordering of table
    [RescueAVR.ino]
2013-10-01 Version 0.94
    - wrong version number
    - green LED did not work in conjunction with Tiny HVPP
    - added some diagnostic message for non-int. mode
    [RescueAVR.ino]
2013-10-04 Version 2.0
    - nicer UI
    - now, it can also be used on an Arduino
    - added Fritzing wiring sketches
2013-10-04 Fritzing files added
    [RescueAVR-megaX8.fzz, RescueAVR-tinyX4.fzz, RescueAVR-tinyX5.fzz]
2018-02-05 Add const keyword to all PROGMEM variables
    Modern versions of AVR-GCC require that all PROGMEM variables be declared const. Without these keywords the sketch does not compile when using any recent version of Arduino AVR Boards, etc.:
    RescueAVR:58: error: variable 'at90s2313' must be const in order to be put into read-only section by means of '__attribute__((progmem))'
    [RescueAVR.ino]
2021-01-21 V2.3:
    Added ATtiny1634, corrected code for reading OSCCAL values, added 'R'
    to all menus to trigger a reset, and cleaned up the docu
    [RescueAVR.ino]
2024-09-05 V2.6.0 and new PCBs
    [RescueAVR.kicad_pcb, RescueAVR.kicad_sch, RescueAVRAdapter.kicad_pcb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]

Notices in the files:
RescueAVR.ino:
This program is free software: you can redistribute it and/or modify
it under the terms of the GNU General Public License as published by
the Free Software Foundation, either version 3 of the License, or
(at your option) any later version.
